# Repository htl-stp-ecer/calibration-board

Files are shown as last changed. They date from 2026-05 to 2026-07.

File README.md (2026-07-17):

<div align="center">

Calibration Board

# calibration-board

**A companion board for the KIPR Wombat: absolute position from optical flow, and a reference IMU good enough to calibrate the Wombat's own.**

KiCad PCB · STM32F722 firmware · On-board Madgwick fusion · Persistent flash calibration · USB-CDC to LCM bridge






> 📖 Platform documentation at [raccoon-docs.pages.dev](https://raccoon-docs.pages.dev/)

</div>

---

## What this is

There are two things a Wombat can't tell you well on its own.

The first is where it actually is. Wheel odometry integrates encoder ticks and trusts them, but wheels slip on seams, on poms and on ramps, and every slipped tick stays in the estimate for the rest of the run. Encoders measure the wheels, not the ground.

The second is whether its IMU is accurate. The Wombat's onboard IMU is fine for checking that a turn was roughly 90°. It isn't good enough to calibrate anything against.

This board addresses both, and it rides on the robot rather than sitting on a bench:

- A PAA5100 optical flow sensor tracks the table surface. Counts are scaled through a stored calibration into centimetres, which gives the robot an absolute position that doesn't depend on whether a wheel spun.
- An ICM-42688-P with Madgwick fusion on an M7 with an FPU provides a gyro reference accurate enough to calibrate the Wombat's onboard IMU against.

Hence the name. It isn't a board you calibrate, it's the board that does the calibrating.

### What it's for

- Calibrating the onboard IMU, with this board as the reference
- Motion teach-in, recording the trajectory that actually happened rather than the one the encoders inferred
- Automated setup routines. Botball allows automated routines during setup time, which is when a robot can locate and calibrate itself before the run starts

This repo isn't a template. It's a working board with an honest bring-up history attached. Read [Known limitations](#known-limitations) before fabbing one.

---

## Calibration that survives a power cycle

Most of the interesting work is in `app/src/paa_cal_module.c` and `app/inc/calib_store.h`.

Calibration lives in flash rather than in a startup routine. Sector 7 (0x08060000, 128 KB) holds a single 64-byte block: PAA scaling (`cx_per_cm`, `cy_per_cm`, `height_mm`), the gyro bias, a magic number, a schema version and a CRC32. The firmware fits in sectors 0 to 3, so 4 to 7 are free. A bad CRC or empty flash falls back to defaults and reports `valid = false`, so the caller knows it has never been calibrated instead of trusting garbage.

The board boots already calibrated. At startup the stored gyro bias is loaded straight into `imu_fusion_init()`, so there's no warm-up and no need to hold the robot still before a match.

Bias is learned continuously and persisted carefully. While the board is at rest, an exponential moving average runs on the raw gyro, and that average is the bias. It's subtracted before Madgwick and before anything is sent over USB. Auto-save only fires when the learned bias drifts more than 0.5 dps from the stored value, only while at rest so the value is trustworthy, and at most every 2 minutes. Each save costs a full sector erase, roughly 1 s and one P/E cycle, so the threshold and interval keep writes down to a few per large temperature swing. Gyro bias drifts around 0.05 dps/°C, which is what the thresholds are sized for.

Flash writes are deferred out of interrupt context into the main loop via a pending flag, because `HAL_FLASHEx_Erase` blocks.

At-rest detection uses a max-min spread across the gyro axes and accel magnitude, with time dwell and hysteresis. It takes about 0.5 s to declare the board still, and exits immediately on motion. Madgwick runs without a magnetometer at the ICM's 1 kHz ODR, so yaw drifts slowly while roll and pitch stay corrected against gravity. A filter step costs about 1 µs on the M7 at 216 MHz.

Commands over USB: `CMD_SET_PAA_CAL` stores new PAA scaling, `CMD_SAVE_GYRO_BIAS` persists the current at-rest average, `CMD_RESET_GYRO_BIAS` clears it. Telemetry goes the other way, with ORIENTATION frames (quaternion, bias, at-rest flag) at 100 Hz and PAA calibration telemetry at 1 Hz.

---

## How it fits together

```
PAA5100 ─┐                                              ┌─ raccoon/calib_board/paa/delta_x
         ├─ SPI ─► STM32F722 ──► USB-CDC ──► host ──────┤─ raccoon/calib_board/icm/accel
ICM-42688-P ─┘     fusion 1 kHz   binary     bridge     ├─ raccoon/calib_board/icm/gyro
                   cal in flash   frames                └─ raccoon/calib_board/status/*
```

`host/` is a C++ bridge (`raccoon-calib-bridge`) that reads binary frames from `/dev/ttyACM*` and republishes them as typed [raccoon-transport](https://github.com/htl-stp-ecer/raccoon-transport) messages. Calibration data flows on the same LCM channels as everything else in RaccoonOS, so BotUI or any other subscriber can plot it live. Status channels republish every second, which means a subscriber that starts late still picks up the current state instead of waiting for an event. A systemd unit is included.

### Firmware architecture

The module registry is Arduino-style. Each sensor is a `module_t` with `setup()` and `loop()`, registered in one array in `app/src/app.c`. An `enabled` flag parks a module without deleting it, which is how the dead BNO is handled.

Modules are started 25 ms apart rather than all at once. Every peripheral draws current at bring-up, and simultaneous init is a step load that can pull a marginal supply into brownout. Staggering flattens the ramp. The capacitor inrush at plug-in happens before this phase and isn't affected.

---

## Bring-up history

The board was designed around a Bosch BNO086, which does sensor fusion on-chip and outputs a quaternion directly. It never came up. After reset the INT line asserts, but the BNO never actively drives MISO, so every packet we read was a threshold artefact from a floating line. SPI mode, clock speed, pull-ups, boot delay and pin states were all ruled out in software, which left a suspected broken CS path. It's parked in the firmware with `.enabled = false /* BNO08x defekt */`.

The ICM-42688-P took over instead: raw 6-axis, with fusion left to us. That's why `imu_fusion.c` exists. Losing the chip that would have done fusion internally is what moved Madgwick onto the STM32, where the bias estimator could be added and the whole pipeline is visible rather than hidden behind a sensor hub.

The HSE crystal also refused to oscillate at first, leaving `HSEON=1, HSERDY=0` and dropping into `Error_Handler` on every boot. That turned out to be an oscillator ground problem and was fixed in the schematic. The firmware runs on HSE now.

---

## Repo layout

| Path | Contents |
|:-----|:---|
| `Firmware/` | STM32CubeMX CMake project, target STM32F722RET6. Capitalised folders are ST-generated, lowercase are ours |
| `Firmware/app/` | Module registry, fusion, calibration store, USB framing |
| `Firmware/drivers/` | Our chip drivers: `bno08x/`, `icm42688p/`, `paa5100/` |
| `Firmware/lib/sh2/` | CEVA BNO08x driver (git submodule) |
| `Firmware/scripts/` | build / flash / debug / uart / swo. Call these rather than ST tools directly |
| `host/` | C++ USB-CDC to raccoon-transport bridge, plus systemd unit |
| `IMU_Extendor_Board/` | KiCad 7+ project: schematic, PCB, BOM, gerbers in `production/` |
| `enclosure/` | OpenSCAD tray and lid, STL/STEP exports (M2 self-tapping, ~55x55 mm PCB) |
| `Component_Datasheets/` | Datasheets plus hand-written analysis (`external_clock_analysis.md`) |
| `docs/` | Toolchain setup, firmware workflow, hardware overview, coding conventions |

---

## Quick start

```bash
git submodule update --init --recursive   # sh2 + raccoon-transport

Firmware/scripts/build.sh          # cmake + ninja
Firmware/scripts/build-docker.sh   # same, in a container, no host arm-gcc needed
Firmware/scripts/flash.sh          # build + flash + verify + start over ST-LINK SWD
Firmware/scripts/uart.sh           # stream the debug console (J703, 115200 8N1)
```

Full setup for a fresh machine: [`docs/toolchain-setup.md`](docs/toolchain-setup.md).

### Catching boot output

Start `uart.sh` before `flash.sh`. The boot `printf` fires within milliseconds of reset, well before you can switch terminals. Two panes:

```bash
# Pane 1, left running:
Firmware/scripts/uart.sh
# Pane 2:
Firmware/scripts/flash.sh
```

If an expected printf never appears, the firmware is more likely hung before that line than the UART is broken. Init exposes debug globals (`g_bno_init_status`, `g_paa_init_status`, `g_bno_stage`, `g_paa_cal_loaded`) that you can read over SWD without re-flashing:

```bash
STM32_Programmer_CLI -c port=SWD mode=HOTPLUG -r32 <addr> 4
```

### The USER LED is a status channel

With no UART adapter attached, the LED is the only thing reporting anything:

| Pattern | Meaning |
|:---|:---|
| 100 ms on / 100 ms off (fast) | init OK, sensor answered, product IDs read |
| 500 ms on / 500 ms off (slow) | setup failed, INT line or clock path suspect |
| 50 ms on / 950 ms off (pulse) | unexpected init return code |

---

## Known limitations

Worth reading before you fab a board or trust a number.

- The BNO086 is dead and disabled. A broken CS path is the suspicion. Software causes were ruled out, so it needs a DMM on `PA4` to `BNO086 CSN` before anyone touches the firmware again.
- USB-C (J101) is not populated. The board runs off the ST-LINK debug cable, which caps its current budget and means it isn't standalone. J101 and the USBLC6 ESD diode need populating per the schematic before it can ride on a robot properly.
- SWO doesn't work with ST-LINK V2 clones. `swo_init` configures TPIU/ITM correctly, but the green clones expose a `T_JTDO` pin that isn't internally wired to their TRACESWO input, and reflashing official ST firmware doesn't fix it. Use UART4 instead, or a genuine STLINK-V3. `__io_putchar` writes to both sinks, so take whichever you can capture.
- PAA scaling depends on mount height. The defaults assume 19 mm. Changing the height changes counts-per-cm, so recalibrate via `CMD_SET_PAA_CAL` after any remount or the absolute position will be confidently wrong.
- The flash layout assumes small firmware. The calibration block sits in sector 7 because the code fits in sectors 0 to 3. Firmware growing past about 448 KB breaks that.
- Chip-select assignments aren't fully captured in the firmware. Cross-reference the KiCad schematic before wiring up a new sensor.
- `Firmware.ioc` is owned by CubeMX. Regenerating overwrites most of `Core/` and `Drivers/`, so keep code inside the `USER CODE BEGIN/END` markers, or put it in `app/` and call it from `app_main()`.
- Parts of the docs and code comments are in German. This was an internal engineering repo and we haven't translated it.

---

## Part of RaccoonOS

| Repository | What it is |
|:---|:---|
| [raccoon-transport](https://github.com/htl-stp-ecer/raccoon-transport) | The LCM messaging layer this board publishes into |
| [stm32-data-reader](https://github.com/htl-stp-ecer/stm32-data-reader) | Pi to STM32 SPI bridge on the robot itself |
| [raccoon-lib](https://github.com/htl-stp-ecer/raccoon-lib) | Core robotics library, odometry and heading control downstream of this |
| [raccoon-robots](https://github.com/htl-stp-ecer/raccoon-robots) | Real competition robots built on the platform |
| [botui](https://github.com/htl-stp-ecer/botui) | Wombat dashboard, can subscribe to these channels live |
| [documentation](https://raccoon-docs.pages.dev/) | Full platform docs |

---

Built by team `axht-3085`, the Botball team at HTL St. Pölten.

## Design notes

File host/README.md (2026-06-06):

# raccoon-calib-bridge

USB-CDC → `raccoon-transport` bridge for the calibration-board firmware
(`../Firmware`).  Reads binary frames from `/dev/ttyACM*`, publishes
typed messages on `raccoon/calib_board/...` channels, and reports board
+ per-sensor status on dedicated status channels.

## Channels

| Channel | Type | Units / payload |
|---|---|---|
| `raccoon/calib_board/icm/accel` | `vector3f_t` | g (x,y,z) |
| `raccoon/calib_board/icm/gyro` | `vector3f_t` | dps (x,y,z) |
| `raccoon/calib_board/icm/temperature` | `scalar_f_t` | °C |
| `raccoon/calib_board/paa/delta_x` | `scalar_i32_t`  | raw counts |
| `raccoon/calib_board/paa/delta_y` | `scalar_i32_t`  | raw counts |
| `raccoon/calib_board/paa/squal` | `scalar_i32_t`  | 0..169 surface qual. |
| `raccoon/calib_board/paa/shutter` | `scalar_i32_t`  | raw 16-bit |
| `raccoon/calib_board/paa/motion` | `scalar_i32_t`  | bitfield |
| `raccoon/calib_board/status/board` | `string_t` | `connected`/`disconnected` |
| `raccoon/calib_board/status/port` | `string_t` | `/dev/ttyACMn` or `(none)` |
| `raccoon/calib_board/status/icm` | `string_t` | `ok` / `init_failed:<reason>` |
| `raccoon/calib_board/status/paa` | `string_t` | `connected` / `absent` / `init_failed:<reason>` |
| `raccoon/calib_board/status/stats` | `string_t` | JSON (counters) |

All status channels are republished every 1 s so a subscriber that comes
up after the bridge can pick up current state without having to wait
for an event.

## Build

```bash
git submodule update --init --recursive   # first time only
scripts/build.sh                          # native build → build/raccoon-calib-bridge
CMAKE_BUILD_TYPE=Debug scripts/build.sh   # debug build
```

`scripts/build.sh` will auto-init the submodule and also accepts the
sibling `../../raccoon-transport` directory as a fallback when the
workspace is checked out flat.

## Run (foreground)

```bash
build/raccoon-calib-bridge                          # auto-detect /dev/ttyACM*
build/raccoon-calib-bridge --port /dev/ttyACM0      # explicit
CALIB_BRIDGE_LOG=debug build/raccoon-calib-bridge   # noisy
```

The bridge **runs even when the board is not connected** — it just
publishes `status/board = "disconnected"` and retries the open every
500 ms.  When the board appears it auto-attaches; when it disappears it
goes back to retrying.  Same for the PAA5100 (status frames from the
firmware report PAA connect/disconnect events mid-run).

## Install as systemd service

```bash
scripts/build.sh
scripts/install.sh           # asks for sudo
systemctl status   raccoon-calib-bridge
journalctl -u      raccoon-calib-bridge -f
```

Override defaults in `/etc/default/raccoon-calib-bridge`, then
`systemctl restart raccoon-calib-bridge`.

## Status semantics

* `status/board = connected`     — port open, bytes flowing
* `status/board = disconnected`  — port closed (either never opened, lost, or silence-timeout fired)
* `status/icm   = ok`            — ICM init reported OK (from firmware STATUS frame, or inferred from incoming ICM frames)
* `status/icm   = init_failed:…` — firmware reported a specific failure
* `status/paa   = connected`     — firmware STATUS frame reports PAA init OK
* `status/paa   = absent`        — firmware STATUS frame reports no PAA present
* `status/paa   = board_disconnected` — board itself is down; PAA state unknown

## Protocol

Frames are documented in `shared/calib_bridge/Framing.h` and **must stay
byte-identical** to `../Firmware/app/inc/framing.h`.  Same CRC, same
endianness, same payload layout.  If you change one, change the other.

## Layout

```
host/
├── CMakeLists.txt
├── README.md
├── scripts/
│   ├── build.sh
│   └── install.sh
├── shared/
│   └── calib_bridge/Framing.h     # frame format + decoders
├── src/
│   ├── main.cpp
│   └── calib_bridge/
│       ├── Application.{h,cpp}    # main loop, reconnect, status
│       ├── Channels.h             # channel name constants
│       ├── Config.{h,cpp}         # CLI + ENV config
│       ├── FrameDecoder.{h,cpp}   # sync/CRC/dispatch
│       ├── Publisher.{h,cpp}      # raccoon::Transport adapter
│       └── SerialPort.{h,cpp}     # /dev/ttyACM* RAII + autodetect
├── systemd/
│   └── raccoon-calib-bridge.service
└── third_party/
    └── raccoon-transport/   # git submodule
```

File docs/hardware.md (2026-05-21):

# Hardware Overview

The calibration board is a carrier PCB for the Raccoon Botball robot, designed to characterise IMU drift and bias prior to deployment. KiCad sources live in `IMU_Extendor_Board/`; BOM in `IMU_Extendor_Board.csv`, production gerbers and pick&place in `IMU_Extendor_Board/production/`.

## MCU

**STM32F722RET6** — Cortex-M7 @ up to 216 MHz, FPU (fpv5-sp-d16), 512 KB Flash, 256 KB RAM, LQFP-64. Powered via 3.3 V (linear regulator on board; datasheet in `Component_Datasheets/3V3_Linear_Regulator_files/`).

### Pin assignments (from `Firmware.ioc`)

| Function | Pins |
|---|---|
| **SWD** | PA13 (SWDIO), PA14 (SWCLK), PB3 (SWO) |
| **UART4** (debug console) | PA0 (TX → adapter RX), PA1 (RX ← adapter TX), 115200 8N1, broken out on J703. Stream with `Firmware/scripts/uart.sh`. Common GND required, **do not** also bridge VCC if board is powered via ST-LINK. |
| **SPI1** | PA5 (SCK), PA6 (MISO), PA7 (MOSI) — IMU #1 candidate bus |
| **SPI2** | PB10 (SCK), PC2 (MISO), PC3 (MOSI) — IMU #2 candidate bus |
| **SPI3** | PC10 (SCK), PC11 (MISO), PC12 (MOSI) — IMU #3 candidate bus |
| **USB OTG FS** | PA9 (VBUS), PA11 (D-), PA12 (D+) |
| **External interrupts** | PA15 (EXTI15), PC4 (EXTI4) — likely IMU INT lines |
| **HSE** | PH0/PH1 (main oscillator) |
| **LSE** | PC14/PC15 (RTC oscillator) |
| **GPIO outputs** | PA2, PA3, PA4, PB0–B2, PB11–B15, PC6–C9, PD2 — CS lines, LEDs, IMU reset/boot |

Three independent SPI buses suggest the board is wired for simultaneous evaluation of multiple IMUs; chip-select assignments are not yet captured in the firmware and need cross-referencing with the KiCad schematic.

## Candidate IMUs

Datasheets present in `Component_Datasheets/` for both options:

- **Bosch BNO080 / BNO085** — sensor fusion built in (quaternion output over SPI/I2C/UART, "Sensor Hub"). Crystal: ECS-327KE 32.768 kHz (datasheet present).
- **TDK InvenSense ICM-42688-P** — 6-axis (3-axis accel + 3-axis gyro), low-noise. Raw output, fusion done on host.

Both can be populated alongside each other on the same carrier (one per SPI bus), enabling side-by-side bias/drift comparison.

## Oscillators

- **ABM8G-12.000MHZ-18-D2Y-T** — 12 MHz HSE for the STM32 (datasheet: `ABM8G-12.000MHZ-...pdf`)
- **ABM8-272-T3** — additional crystal, role TBD from schematic (likely IMU clock)
- **ECS-327KE** — 32.768 kHz, used by BNO080/085 per `external_clock_analysis.md`

The hand-written analysis in `Component_Datasheets/external_clock_analysis.md` documents the clocking strategy — read it before changing any RCC config in `Firmware.ioc`.

## Power

3.3 V linear regulator (see `3V3_Linear_Regulator_files/`); USB OTG FS handles bus-powered operation.

## KiCad project

Open `IMU_Extendor_Board/IMU_Extendor_Board.kicad_pro` in KiCad 7+. Custom symbols and footprints in `Component_Lib/`; design rules in `IMU_Extendor_Board.kicad_dru`. Production drop is `production/` (zipped as `production.zip`).

For agent-friendly inspection of the schematic, install `kicad-cli` (`sudo apt install kicad-cli`) and export to PDF/netlist:

```bash
cd IMU_Extendor_Board
kicad-cli sch export pdf -o schematic.pdf IMU_Extendor_Board.kicad_sch
kicad-cli sch export netlist -o schematic.net IMU_Extendor_Board.kicad_sch
kicad-cli sch export bom -o bom.csv IMU_Extendor_Board.kicad_sch
```

The raw `.kicad_sch` is S-expression text (~21k lines) — parseable but verbose; prefer the exports for any structural analysis.

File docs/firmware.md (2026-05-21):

# Firmware Workflow

Day-to-day build, flash, and debug for the STM32F722RET6 firmware. For one-time setup see `toolchain-setup.md`.

## Helper scripts

All workflow goes through `Firmware/scripts/`. They work from any CWD, source `_common.sh` for paths, and filter `libusb:` noise + ANSI escapes out of ST tool output.

| Script | What it does |
|---|---|
| `build.sh [Debug\|Release]` | Configure (if needed) + ninja build. Default: Debug. |
| `build-docker.sh [Debug\|Release]` | Same as `build.sh` but inside a Debian builder container — no host arm-none-eabi-gcc / cmake / ninja required. Image is auto-built on first run. |
| `flash.sh [Debug\|Release]` | `build.sh` then flash + verify + start on SWD. |
| `reset.sh` | Software-reset target. No re-flash. |
| `erase.sh` | Full chip erase under reset. Use when target is bricked / unresponsive. |
| `gdbserver.sh` | Foreground `ST-LINK_gdbserver` on `:61234`. For IDE external-server debug configs. |
| `debug.sh` | `build.sh` + gdbserver in background + interactive `arm-none-eabi-gdb` with `load` and `tbreak main`. |
| `uart.sh` | Stream UART4 `printf` output (J703, 115200 8N1) from the USB-UART adapter. Auto-detects CP2102, falls back to `/dev/ttyUSB0`. Logs to `$BUILD_DIR/uart.log`. |
| `swo.sh` | Stream SWO/ITM trace from PB3 via `STM32_Programmer_CLI -startswv`. **Requires a genuine ST-LINK V3** — most ST-LINK V2 clones (green USB stick) don't route TRACESWO internally. Logs to `$BUILD_DIR/swv.log`. See troubleshooting below. |

### Env overrides

| Var | Default | Effect |
|---|---|---|
| `BUILD_TYPE` | `Debug` | Selects CMake preset and build dir |
| `SWD_FREQ_KHZ` | `4000` | ST-LINK SWD clock |
| `GDB_PORT` | `61234` | Port for `gdbserver.sh` / `debug.sh` |
| `PROG_CLI`, `GDB_SERVER`, `GDB` | binaries on PATH | Override tool binaries |
| `UART_DEV` | auto (CP2102) / `/dev/ttyUSB0` | Serial device for `uart.sh` |
| `UART_BAUD` | `115200` | Baud rate for `uart.sh` (must match `MX_UART4_Init`) |
| `SYSCLK_MHZ` | `192` | HCLK in MHz for `swo.sh` (must match `swo_init()` call) |
| `SWV_PORT` | `0` | ITM stimulus port for `swo.sh` |

Example: release build, flashed at slower clock:

```bash
SWD_FREQ_KHZ=1800 Firmware/scripts/flash.sh Release
```

### Docker builder

`Firmware/Dockerfile` defines a `debian:trixie-slim` image with `gcc-arm-none-eabi` 14.2 + cmake + ninja. The host source tree is bind-mounted at **the same absolute path** inside the container, so the paths CMake bakes into `CMakeCache.txt` are valid both inside and outside the container. Consequence: you can freely alternate `build-docker.sh` and `build.sh` — the build cache is shared and reused, no clean-and-reconfigure dance.

Override the image tag with `BUILD_DOCKER_IMAGE=…`. Rebuild the image after editing the Dockerfile with `docker build -t raccoon-calibration-firmware:latest Firmware/`.

Flashing still happens host-side (`flash.sh`) — the container deliberately does **not** contain `STM32_Programmer_CLI`. ST's license forbids redistributing it, and USB passthrough for ST-LINK is fragile across hosts.

## Project structure

```
Firmware/
├── CMakeLists.txt             # User-editable
├── CMakePresets.json          # Debug/Release presets, Ninja, gcc-arm-none-eabi toolchain
├── Firmware.ioc               # STM32CubeMX project — regenerates Core/ + Drivers/
├── STM32F722XX_FLASH.ld       # Linker script (512 KB flash, 256 KB RAM)
├── startup_stm32f722xx.s      # Reset handler + vector table
├── cmake/
│   ├── gcc-arm-none-eabi.cmake     # Toolchain file (cortex-m7 + fpv5-sp-d16)
│   └── stm32cubemx/                # CubeMX-generated HAL driver list
├── Core/
│   ├── Inc/{main,stm32f7xx_hal_conf,stm32f7xx_it}.h
│   └── Src/{main,stm32f7xx_hal_msp,stm32f7xx_it,syscalls,sysmem,system_stm32f7xx}.c
├── Drivers/
│   ├── CMSIS/                       # ARM CMSIS + STM32F7xx device headers
│   └── STM32F7xx_HAL_Driver/        # ST HAL sources
└── scripts/                         # See above
```

**Touch-zone rules:**

- `Core/Src/main.c` and friends: only edit inside `/* USER CODE BEGIN ... */` … `/* USER CODE END ... */` markers. CubeMX overwrites everything outside on regeneration.
- `Firmware.ioc`: edit only in STM32CubeMX. Regenerate with **Project → Generate Code** from the CubeMX UI (or `stm32cubemx` CLI). Commit the regenerated diff together with the `.ioc` change.
- `cmake/stm32cubemx/`: auto-generated. Do not hand-edit.
- `CMakeLists.txt`: user-owned. Add your sources to `target_sources()`, includes to `target_include_directories()`.

## CLion integration

The `.idea/debugServers/ST_LINK.xml` already points at the installed CubeCLT paths. Recommended run-configs:

**1. Flash (Shell Script)**
- Script path: `$ProjectFileDir$/scripts/flash.sh`
- Working dir: `$ProjectFileDir$`
- Before launch: *(none — `flash.sh` builds itself)*

**2. Debug (Embedded GDB Server)**
- Target: `Firmware` (CMake)
- Executable binary: `Firmware`
- `'target remote' args`: `tcp:localhost:61234`
- GDB Server: `$ProjectFileDir$/scripts/gdbserver.sh`
- Reset command: `monitor reset`

With these two, "Run" flashes, "Debug" attaches GDB through the same gdbserver the script starts.

## Headless / AI agent workflow

Everything runs without CLion. Example one-shot edit→flash cycle for an agent:

```bash
# edit code
$EDITOR Firmware/Core/Src/main.c
# build + flash + run, single command, works from any CWD
Firmware/scripts/flash.sh
# observe printf output via UART4 on PA0/PA1 (J703) — start before flash to catch boot lines
Firmware/scripts/uart.sh
```

`__io_putchar` writes to both SWO/ITM (PB3) and UART4 — printf goes out whichever path you can capture. SWO needs a working trace probe (see troubleshooting); UART4 needs only a 3.3 V USB-UART adapter on J703 with GND tied to board ground.

For a brick (target won't enumerate on SWD under normal connect), use connect-under-reset path:

```bash
Firmware/scripts/erase.sh    # uses mode=UR (connect-under-reset) + full erase
Firmware/scripts/flash.sh    # then re-flash
```

## Troubleshooting

| Symptom | Likely cause | Fix |
|---|---|---|
| `Error: No STM32 target found` | Target unpowered, SWD wiring wrong, or BOOT0 stuck | Check 3V3 rail, SWCLK/SWDIO continuity (PA14/PA13), tie BOOT0 low |
| `libusb: error … requires write access` | udev rules not applied | `sudo udevadm control --reload-rules && sudo udevadm trigger` + re-plug ST-LINK |
| `Duplicate preset: "Debug"` from cmake | Local `CMakeUserPresets.json` collides with `CMakePresets.json` | Rename local presets (e.g. `Debug-local`) or delete the user file |
| Verify fails after download | Wrong target / corrupted flash sector | `erase.sh` then retry |
| `swo.sh` prints "Reception Started" then nothing | Clone ST-LINK V2 (green USB stick) — `T_JTDO` pin exists but isn't internally wired to the probe's TRACESWO input. Reflashing the official ST firmware (`/opt/st/stm32cubeclt_1.21.0/STLinkUpgrade.sh -force_prog`) does **not** fix this; the limitation is hardware. | Use `uart.sh` instead, or get an STLINK-V3MINIE. |
| `uart.sh` shows 0 bytes | **UART4 is verified working** — if you see nothing, the cause is almost always one of: (1) `uart.sh` was started *after* `flash.sh`, missing the boot-time burst (most common — the loop's `printf`s may also stop appearing if a driver init blocks the main loop from being reached); (2) **GND not bridged** between USB-UART adapter and board (silent failure); (3) baudrate mismatch (must be 115200, see `MX_UART4_Init`); (4) firmware actually hangs before reaching the first `printf` (rare — `swo_init` + `setvbuf` are the only things ahead of `printf("[boot] …")`). | Start `uart.sh` **before** `flash.sh`, confirm shared GND. To distinguish "MCU hung" from "UART broken", read `g_bno_init_status` / `g_paa_init_status` / `g_bno_stage` via `STM32_Programmer_CLI -c port=SWD mode=HOTPLUG -r32 <addr> 4` — if the stage variable advances, the firmware runs and the silence is on the host/wiring side. |
| GDB server: `Port 61234 already in use` | Previous `gdbserver.sh` still running | `pkill -f ST-LINK_gdbserver` or set `GDB_PORT=61235` |

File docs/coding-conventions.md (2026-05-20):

# Firmware coding conventions

Applies to all C code under `Firmware/` **except** `Firmware/Core/`,
`Firmware/Drivers/`, and `Firmware/lib/` — those are STM32CubeMX-generated or
third-party and follow their upstream styles.

## Folder layout

```
Firmware/
├── Core/                     # STM32CubeMX-owned. Hands off (regenerates).
├── Drivers/                  # ST HAL + CMSIS. Hands off (regenerates).
├── app/                      # Application logic (state machines, glue).
│   ├── inc/                  # Public headers
│   └── src/                  # Implementations
├── drivers/                  # Project-owned hardware drivers.
│   └── <chip>/
│       ├── inc/<chip>.h      # Public API
│       └── src/<chip>.c
├── lib/                      # Third-party (submodules, vendored libs).
└── scripts/                  # Build / flash / debug helpers.
```

Rule of thumb: **capitalised folders are ST-generated, lowercase folders are
ours**. New code goes into lowercase.

## Naming

| Kind | Style | Example |
|---|---|---|
| Functions, variables | `snake_case` | `bno08x_read_quat()` |
| Module-public API | `<module>_` prefix | `bno08x_init()`, `app_main()` |
| Module-internal | `static`, no prefix | `static void parse_report(...)` |
| Types | `snake_case_t` | `bno08x_status_t` |
| Macros, constants | `UPPER_SNAKE` | `BNO08X_MAX_FRAME` |
| Enum values | `UPPER_SNAKE`, type-prefixed | `BNO08X_OK` |
| Files | lowercase, match module name | `bno08x.c`, `bno08x.h` |

Never `typedef` away pointers (no `bno08x_t *` hidden as `bno08x_handle`) —
explicit pointers read better.

## Headers

- Use `#pragma once`, not include guards. GCC supports it, less boilerplate.
- Public API only in `inc/`. Internal helpers in `src/`, optionally as
  `<module>_priv.h` next to the `.c`.
- Forward-declare in headers where possible; full `#include` only when the
  header needs the type's layout.
- One module = one `.c` + one `.h`. If a `.c` grows beyond ~500 lines, split.

## Functions and state

- Everything file-local is `static`. If something isn't in the public header,
  it must be `static`.
- No global variables outside of HAL-generated handles in `Core/`. Module
  state goes in a `static` struct inside the `.c`.
- Functions return `0` on success and negative `errno`-style codes on failure,
  or a dedicated `<module>_status_t` enum (preferred when codes are
  module-specific). Pick one per module and stick to it.
- Out-parameters via pointer, never by returning structs by value (varies
  across ABIs and copies on Cortex-M).

## main.c and USER CODE markers

- `Core/Src/main.c` is regenerated by CubeMX. The `/* USER CODE BEGIN ... */`
  markers are the only safe place for hand edits — anything outside gets
  overwritten.
- Keep `main.c` thin: peripheral init (CubeMX does this) + one call to
  `app_main()` in `USER CODE BEGIN 2`. Real logic lives in `app/`.
- Don't put driver-level code into `USER CODE` blocks. Add a module under
  `drivers/<chip>/` and call it from `app/`.

## Comments

- Default: no comments. Names should carry the meaning.
- Write a comment only when the **why** is non-obvious: a hidden constraint
  from a datasheet, a workaround for a known erratum, a subtle ordering
  requirement. Reference the source (`§7.3.2 of DS13855`) when relevant.
- Don't comment what the code does. Don't reference tickets, PRs, or
  "added for X" — that's git/PR territory.

## Includes order

```c
#include "this_module.h"        /* own header first — verifies it's self-contained */

#include <stdint.h>             /* C standard library */
#include <string.h>

#include "main.h"               /* HAL / ST */
#include "stm32f7xx_hal.h"

#include "sh2.h"                /* third-party */

#include "app.h"                /* other project modules */
```

Blank line between groups.

## Build hygiene

- Build artifacts go to `Firmware/build/<BuildType>/`. Never commit them.
- The `.ioc` file is owned by CubeMX; don't hand-edit unless you know what
  you're undoing on the next regen.
- `CMakeUserPresets.json` is local-only (gitignored). Use it for per-machine
  paths; never `CMakePresets.json`.

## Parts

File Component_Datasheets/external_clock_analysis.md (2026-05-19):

# External Clock vs. Internal Clock — Impact Analysis
## BNO08X & ICM-42688-P for Dual-IMU Robotics

---

## 1. ICM-42688-P

### 1.1 Clock Source Specifications (from Table 4, section 3.3.2)

| Parameter | Internal RCOSC (CLK_SEL=00) | Internal PLL (CLK_SEL=01, gyro active) | External CLKIN |
|---|---|---|---|
| Initial tolerance at 25 °C | ±3 % | ±1.5 % | — |
| Variation over temp (−40 to +85 °C) | ±3 % | ±2 % | — |
| ODR uncertainty (section 4.10) | **±8 %** (±80 000 ppm) | **±1 %** (±10 000 ppm) | **±50 ppm** (with 50 ppm source) |
| Clock frequency | internal | internal | 31–50 kHz, typ. 32 kHz |

> The datasheet (section 4.10) explicitly states ODR uncertainty can be as high as ±8 % in RCOSC mode and ±1 % in PLL mode. A 50 ppm CLKIN source reduces this to ±50 ppm in both modes.

---

### 1.2 Calculations — ICM-42688-P

**Assumptions:** nominal ODR = 1000 Hz, robotics run of T = 10 s, host uses sensor sample count as time reference (no external timestamping).

#### 1.2.1 Sample count drift

| Clock source | Actual ODR range | Samples in 10 s | Error vs. 10 000 samples |
|---|---|---|---|
| RCOSC (±8 %) | 920–1080 Hz | 9 200–10 800 | **±800 samples** |
| PLL (±1 %) | 990–1010 Hz | 9 900–10 100 | ±100 samples |
| CLKIN 50 ppm | 999.95–1000.05 Hz | 9 999.5–10 000.5 | **±0.5 samples** |

#### 1.2.2 Timing error (dead-reckoning with sample count × nominal dt)

Formula: `time_error = T × clock_error_fraction`

| Clock source | Time error after 10 s | Time error after 60 s |
|---|---|---|
| RCOSC (±8 %) | **±800 ms** | **±4.8 s** |
| PLL (±1 %) | ±100 ms | ±600 ms |
| CLKIN 50 ppm | **±0.5 ms** | **±3 ms** |

#### 1.2.3 Gyroscope angle integration error

Dead-reckoning angle: if the sensor's dt is wrong, integrated heading is wrong by the same fraction.

Formula: `angle_error = total_angle_turned × clock_error_fraction`

**Scenario A — single 360° turn taking 1 s:**

| Clock source | Angle error |
|---|---|
| RCOSC (±8 %) | **±28.8°** |
| PLL (±1 %) | ±3.6° |
| CLKIN 50 ppm | **±0.018°** |

**Scenario B — 90° turn (typical Botball maneuver) at 180 °/s:**

| Clock source | Angle error |
|---|---|
| RCOSC (±8 %) | **±7.2°** |
| PLL (±1 %) | ±0.9° |
| CLKIN 50 ppm | **±0.0045°** |

#### 1.2.4 Sensitivity (scale factor) error from clock

From section 4.10: "Any clock uncertainty directly impacts gyroscope sensitivity at the system level."  
The scale factor error is proportional to ODR error.

| Clock source | Gyro sensitivity error |
|---|---|
| RCOSC | ±8 % |
| PLL | ±1 % |
| CLKIN 50 ppm | ±0.005 % |

#### 1.2.5 ODR Frequency Scaling with CLKIN

When CLKIN ≠ 32 kHz, actual ODR scales linearly (section 12.5):

```
ODR_actual = ODR_nominal × (f_CLKIN_kHz / 32)
```

Example: CLKIN = 32.768 kHz → ODR at nominal 1000 Hz = 1000 × (32.768/32) = **1024 Hz**  
This is predictable and compensatable; internal clock drift is not.

---

### 1.3 Improvement Factor — CLKIN vs. Internal

| Comparison | ODR improvement | Timing improvement |
|---|---|---|
| CLKIN over RCOSC | **1 600×** (80 000 ppm → 50 ppm) | **1 600×** |
| CLKIN over PLL | **200×** (10 000 ppm → 50 ppm) | **200×** |

---

## 2. BNO08X

### 2.1 Clock Source Options (section 1.2.1, Figures 1-7 to 1-10)

| Source | CLKSEL0 | CLKSEL1 | Notes |
|---|---|---|---|
| Crystal 32.768 kHz | 0 or NC | Connected to crystal | Recommended: 50 ppm, 12.5 pF load |
| External clock signal | 1 | 1 | Input on XIN32 (pin 27) |
| Internal oscillator | 1 | 0 or NC | **Not usable with UART-SHTP or UART-RVC** |

> CEVA recommends 50 ppm tolerance for external clock/crystal.

### 2.2 Performance Specifications

The performance table (Figure 6-14, section 6.7) is explicitly stated to apply **when using an external clock or crystal**.  
No separate performance specification is provided for the internal oscillator.

| Sensor output | Metric | Value (external clock/crystal) |
|---|---|---|
| Rotation Vector | Dynamic rotation error | 3.5° |
| Rotation Vector | Static rotation error | 2.0° |
| Gaming Rotation Vector | Dynamic non-heading error | 2.5° |
| Gaming Rotation Vector | Static non-heading error | 1.5° |
| Gaming Rotation Vector | **Heading drift** | **0.5°/min** |
| Geomagnetic Rotation Vector | Dynamic rotation error | 4.5° |
| Gyroscope | Dynamic accuracy | 3.1°/s |
| Accelerometer | Dynamic accuracy | 0.35 m/s² |

### 2.3 Calculations — BNO08X

The BNO08X runs its SH-2 fusion firmware off its reference clock. The clock feeds both sensor sampling timing and the algorithm's internal time reference.

#### 2.3.1 Heading drift over time

With external 50 ppm clock (spec):

| Time | Max heading drift |
|---|---|
| 1 min | 0.5° |
| 2 min (Botball match) | **1.0°** |
| 5 min | 2.5° |

With internal oscillator — no official figure given. Typical RC oscillators drift ±1–3 % from nominal. Using conservative ±1 % as an estimate (consistent with what similar CEVA/Bosch parts specify):

| Time | Estimated heading drift (internal, ±1 %) |
|---|---|
| 1 min | ~30–150× worse, estimated **15–75°/min** |
| 2 min (Botball match) | estimated **30–150°** cumulative |

> These internal clock figures are **estimated** — the BNO08X datasheet does not publish internal oscillator accuracy. The only official performance numbers are for external clock/crystal.

#### 2.3.2 Timestamp accuracy

The BNO08X attaches timestamps to sensor reports (SHTP protocol). With a 50 ppm external clock:

| Scenario | Timestamp error after 10 s | After 60 s |
|---|---|---|
| External 50 ppm | ±0.5 ms | ±3 ms |
| Internal oscillator (est. ±1 %) | ±100 ms | ±600 ms |

---

## 3. Dual-IMU Fusion — Synchronization Impact

Your setup uses both IMUs simultaneously to combine their strengths (BNO08X: stable fused orientation; ICM-42688-P: low-noise raw 6-axis at high rate). Synchronization between them is critical for correct data fusion.

### 3.1 Without shared external clock

Each sensor runs on its own independent clock:
- ICM-42688-P internal RCOSC: up to ±8 % ODR
- BNO08X internal oscillator: unknown, estimated ±1 %
- Relative clock error: up to ±9 % combined

**Sample alignment error between IMUs (no shared clock, RCOSC worst case):**

| ODR | Nominal sample period | Max alignment error | After 1 s |
|---|---|---|---|
| 100 Hz | 10 ms | ±9 % × 10 ms = ±0.9 ms per sample | Samples can differ by up to 90 ms in accumulated timing |
| 1000 Hz | 1 ms | ±0.09 ms per sample | up to 90 ms accumulated |

After just 1 second, the two sensors' sample clocks can be 90 ms apart from each other. Any data fusion algorithm that assumes "simultaneous" samples will be correlating data that is up to 90 ms apart.

### 3.2 With shared external 32.768 kHz clock

Both IMUs locked to the same reference:
- ICM-42688-P: ODR error ±50 ppm
- BNO08X: timestamp error ±50 ppm
- Relative alignment error: < ±100 ppm combined

| ODR | Nominal sample period | Max alignment error (shared clock) |
|---|---|---|
| 100 Hz | 10 ms | ±1 µs |
| 1000 Hz | 1 ms | ±0.1 µs |

Samples from both IMUs are effectively simultaneous.

### 3.3 Synchronization improvement summary

| Scenario | Sample alignment error (1 s) | Improvement |
|---|---|---|
| No external clock (RCOSC) | ~90 ms | — |
| No external clock (PLL) | ~10 ms | 9× |
| Shared 50 ppm CLKIN | **< 0.1 ms** | **900×** |

---

## 4. Verdict for Botball Robotics

| Aspect | Without external clock | With external 32.768 kHz clock |
|---|---|---|
| ICM-42688-P ODR accuracy | ±8 % (RCOSC) or ±1 % (PLL) | **±0.005 %** |
| Dead-reckoning heading error per 90° turn | ±7.2° (RCOSC) | **±0.0045°** |
| BNO08X heading drift (2-min run) | unknown / possibly >30° | **≤1.0°** |
| Dual-IMU sample alignment after 1 s | up to 90 ms offset | **< 0.1 ms** |
| Sensor fusion quality | severe interpolation required | essentially perfect alignment |

**Conclusion:** For a dual-IMU robotics application using dead-reckoning and sensor fusion, an external 32.768 kHz clock (50 ppm) shared between both IMUs makes a very large practical difference:
- ICM-42688-P ODR accuracy improves by **200–1600×**
- Sample alignment between the two IMUs improves by ~**900×**
- BNO08X performance specs are only guaranteed with external clock/crystal
- The BNO08X internal oscillator is explicitly forbidden for UART-SHTP and UART-RVC use cases

The external clock hardware cost is a single oscillator (e.g., SiT1532 or similar 32.768 kHz TCXO) plus routing — a very worthwhile investment given the performance gains.

---

*Sources: BNO08X Datasheet Rev. 1.17 (CEVA/Hillcrest), ICM-42688-P Datasheet Rev. 1.6 (TDK InvenSense)*

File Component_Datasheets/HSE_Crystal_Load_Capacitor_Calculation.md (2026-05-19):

# HSE Lastkondensator-Berechnung — ABM8G-12.000MHZ-18-D2Y-T an STM32F411

## Teilenummer-Dekodierung

```
ABM8G - 12.000MHz - 18 - D - 2 - Y - T
         │           │    │   │   │   └─ Tape & Reel (1k/reel)
         │           │    │   │   └───── Freq.-Stabilität: ±30 ppm
         │           │    │   └───────── Freq.-Toleranz: ±20 ppm
         │           │    └───────────── Betriebstemp.: D = -40 … +85 °C
         │           └────────────────── Lastkapazität: 18 pF
         └────────────────────────────── Frequenz: 12,000 MHz
```

---

## Kristall-Parameter (aus Datenblatt)

| Parameter | Wert |
|---|---|
| Frequenz | 12,000 MHz |
| Betriebsmodus | Fundamental |
| Lastkapazität C_L | **18 pF** |
| Shunt-Kapazität C_0 (max) | 5,0 pF |
| Serienersatzwiderstand R_1 (max @ 12 MHz) | **120 Ω** |
| Antriebspegel | 10 … **100 µW** |
| Betriebstemperatur (Option D) | -40 … +85 °C |
| Frequenztoleranz (Option 2) | ±20 ppm |
| Frequenzstabilität (Option Y) | ±30 ppm |
| Gehäuse | 3,2 × 2,5 × 1,0 mm |

---

## Schaltungstopologie — Pierce-Oszillator

```
OSC_IN ──┬── C1 ──┬── GND
         │        │
        [Quarz]  C_stray (parasitär)
         │        │
OSC_OUT ─┴── C2 ──┴── GND
```

Beide Kondensatoren C1 und C2 werden gleich gewählt (C1 = C2 = C_ext).

---

## Formel

Die effektive Lastkapazität, die der Quarz „sieht":

```
C_L = (C1 × C2) / (C1 + C2) + C_stray
```

Mit C1 = C2 = C_ext vereinfacht zu:

```
C_L = C_ext / 2 + C_stray
```

Aufgelöst nach C_ext:

```
C_ext = 2 × (C_L − C_stray)
```

---

## Streukapazität C_stray

| Quelle | Typischer Wert |
|---|---|
| STM32F411 OSC_IN Pin-Kapazität | ~2 pF |
| STM32F411 OSC_OUT Pin-Kapazität | ~2 pF |
| PCB-Leiterbahn / Pad-Streukapazität | ~1–2 pF |
| **Summe C_stray** | **~3 … 5 pF** |

> ST AN2867 gibt ~2 pF pro Pin als typischen Wert für STM32-Familien an.
> Für ein 2-Lagen-PCB wird **C_stray = 4 pF** als realistischer Mittelwert angenommen.

---

## Berechnung

### Nennwert-Berechnung (C_stray = 4 pF)

```
C_ext = 2 × (18 pF − 4 pF)
C_ext = 2 × 14 pF
C_ext = 28 pF
```

Nächster E12-Normwert: **27 pF**

### Verifikation mit C_ext = 27 pF

```
C_L_eff = 27 pF / 2 + 4 pF = 13,5 pF + 4 pF = 17,5 pF  (−2,8 % vom Sollwert)
```

### Sensitivitätsanalyse

| C_stray | C_ext (berechnet) | Nächster E12-Wert | C_L_eff | Abweichung |
|---|---|---|---|---|
| 3 pF | 30 pF | 30 pF | 18,0 pF | 0 % ✓ |
| **4 pF** | **28 pF** | **27 pF** | **17,5 pF** | **−2,8 %** |
| 5 pF | 26 pF | 27 pF | 18,5 pF | +2,8 % |

27 pF liegt im Zentrum der C_stray-Unsicherheit und ist der robusteste Normwert.
Die frequenzmäßige Auswirkung einer ±3 %-Abweichung bei C_L ist kleiner als die
Frequenztoleranz des Quarzes (±20 ppm) — unkritisch.

---

## Anlaufbedingung (Negativwiderstand-Prüfung)

Der Pierce-Oszillator startet sicher, wenn gilt:

```
gm_vorhanden > gm_min = SF × R1 × (ω × C_ext)²
```

Mit Sicherheitsfaktor SF = 5, R1 = 120 Ω, C_ext = 27 pF, ω = 2π × 12 MHz:

```
ω = 2π × 12 × 10⁶ = 75,40 × 10⁶ rad/s

ω × C_ext = 75,40 × 10⁶ × 27 × 10⁻¹² = 2,036 × 10⁻³ S

gm_min = 5 × 120 Ω × (2,036 × 10⁻³)²
       = 600 × 4,144 × 10⁻⁶
       = 2,49 × 10⁻³ A/V
       ≈ 2,5 mA/V
```

Der STM32F411 HSE-Oszillator liefert typisch **10–25 mA/V** (gem. AN2867),
also einen Sicherheitsfaktor von ca. 4–10× über dem Minimum. Anlauf ist gesichert.

> Hinweis: Der R_1 von 120 Ω ist höher als beim vorherigen Kristall (50 Ω),
> daher ist das gm_min hier ~12× größer. Der Anlaufspielraum ist ausreichend,
> aber geringer als bei Quarzen mit niedrigerem ESR.

---

## Antriebspegel-Abschätzung (kritisch)

```
P_drive ≈ ½ × R1 × (ω × C_L × V_pp)²
```

| V_pp | P_drive | Bewertung |
|---|---|---|
| 0,7 V | 43 µW | ✓ innerhalb Spec (10–100 µW) |
| 0,9 V | 90 µW | ✓ knapp innerhalb Spec |
| 1,0 V | **111 µW** | **✗ überschreitet 100 µW max** |
| 1,5 V | 250 µW | ✗ deutlich zu hoch |

**Rechenweg für V_pp = 1,0 V:**
```
ω × C_L = 75,40 × 10⁶ × 18 × 10⁻¹² = 1,357 × 10⁻³ S

P_drive = ½ × 120 × (1,357 × 10⁻³ × 1,0)²
        = 60 × 1,841 × 10⁻⁶
        = 110,5 µW  → überschreitet Max. von 100 µW
```

> **Achtung:** Der maximale Antriebspegel dieses Quarzes beträgt nur 100 µW.
> Der STM32F411-Oszillator kann bei 3,3 V Versorgung Amplituden von 1–2 V
> erzeugen, was den Quarz übersteuert und seine Lebensdauer verkürzt.
>
> **Empfehlung:** Einen Serienwiderstand R_S = 100 … 200 Ω in Serie mit
> OSC_IN schalten (zwischen MCU-Pin und Quarz). Dies dämpft die Amplitude
> und begrenzt den Antriebspegel. Typischer Startwert: **R_S = 100 Ω**.

### Antriebspegel mit R_S = 100 Ω (bei V_pp = 1,0 V)

Der Strom durch den Kristall-Zweig:

```
I_peak = V_pp / (R1 + R_S) × (ω × C_L) / ω  ... (vereinfacht für Abschätzung)
P_crystal ≈ ½ × R1 × I_peak²
          = ½ × R1 / (R1 + R_S)² × (V_pp × ω × C_L)²
          = ½ × 120 / (120 + 100)² × (1,357 × 10⁻³)²
          = 60 / 48400 × 1,841 × 10⁻⁶  ... (inkl. Faktor V²)
```

Vereinfachte Näherung: P skaliert mit (R1 / (R1+R_S)²) × V_pp²:

```
P_drive_mit_RS ≈ P_drive_ohne_RS × R1 / (R1 + R_S)
               = 110,5 µW × 120 / 220
               ≈ 60 µW  ✓
```

Mit R_S = 100 Ω liegt der Antriebspegel bei ~60 µW — sicher im Spec-Fenster.

---

## Ergebnis

| Bauteil | Wert | Toleranz | Dielektrikum |
|---|---|---|---|
| C1 (OSC_IN nach GND) | **27 pF** | ±5 % | C0G/NP0 |
| C2 (OSC_OUT nach GND) | **27 pF** | ±5 % | C0G/NP0 |
| R_S (in Serie mit OSC_IN) | **100 Ω** | ±5 % | — |

**C0G/NP0 zwingend erforderlich** — X5R/X7R haben spannungs- und
temperaturabhängige Kapazität und verschlechtern die Frequenzgenauigkeit.

**Layout-Hinweise:**
- C1 und C2 so nah wie möglich an die Quarz-Pads platzieren
- R_S direkt am OSC_IN-Pin des STM32 (nicht am Quarz-Pin) platzieren
- Leiterbahnen zwischen Quarz und MCU-Pins so kurz wie möglich halten
- Kein Ground-Pour direkt unter den Quarz-Leiterbahnen (erhöht C_stray)
- Quarz und Kondensatoren mit eigenem GND-Polygon abschirmen,
  verbunden am AGND-Pin des STM32

---

## Referenzen

- ABM8G Datenblatt, Abracon, Rev. 08.13.15
- STM32F411xC/xE Datenblatt DS10314, ST Microelectronics
- AN2867 "Oscillator design guide for STM32 microcontrollers", ST
- RM0383 STM32F411 Reference Manual

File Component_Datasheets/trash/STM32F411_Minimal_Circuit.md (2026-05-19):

# STM32F411RETx — Minimalbeschaltung (SWD)

> Quelle: DS10314 Rev 8, §3.13–3.15, §6.3.17, Figure 17, Table 56

---

## 1. Stromversorgung

| Pin | Kondensator | Hinweis |
|---|---|---|
| Jedes VDD/VSS-Paar | 100 nF + 1× 4,7 µF (gesamt) | Keramik, so nah wie möglich |
| VDDA / VSSA | 100 nF + 1 µF | Muss gleiches Potential wie VDD haben |
| **VCAP_1** (Pin 49) | **4,7 µF, ESR < 1 Ω** (X5R/X7R) | Ausgangspin des internen Reglers — **nicht weglassen** |

Betriebsspannung: **1,7 – 3,6 V** (für USB min. 3,0 V)

---

## 2. NRST

- Interner Pull-up: 30–50 kΩ (eingebaut)
- Externer Reset-IC **nicht nötig** — internes POR/BOR übernimmt das
- Empfohlen laut Datenblatt (Figure 32): **100 nF** nach GND (filtert parasitäre Resets)
- Optional: Reset-Taster (NO) zwischen NRST und GND

```
NRST ──[100 nF]── GND
NRST ──[Taster]── GND   (optional)
```

---

## 3. BOOT0

Bestimmt den Boot-Modus beim Reset:

| BOOT0-Pegel | Boot-Modus |
|---|---|
| LOW (GND) | Flash — normaler Betrieb |
| HIGH (VDD) | System Memory (UART/USB-Bootloader) |

```
BOOT0 ──[10 kΩ]── GND        ← normaler Betrieb
BOOT0 ──[Taster]── VDD        ← optional, für Bootloader-Zugang
```

> PDR_ON-Pin existiert beim LQFP64 **nicht** — interner Reset ist immer aktiv.

---

## 4. SWD (Serial Wire Debug)

| Signal | GPIO | LQFP64 Pin | SWD-Connector |
|---|---|---|---|
| SWDIO | PA13 | 46 | Pin 2 |
| SWCLK | PA14 | 37 | Pin 4 |
| SWO (optional) | PB3 | 39 | Pin 6 |
| NRST (optional) | NRST | 7 | Pin 10 |

Kein externer Pull-up/Pull-down auf SWD-Leitungen nötig — interne Beschaltung ausreichend.

**Standard 10-pin ARM Cortex Debug Connector (0,05" / 1,27 mm Raster):**

```
VCC  (1) (2) SWDIO
GND  (3) (4) SWCLK
GND  (5) (6) SWO
Key  (7) (8) NC
GND  (9) (10) NRST
```

---

## 5. Takt

- Interner HSI (16 MHz RC) reicht für Betrieb **ohne USB**
- Kein externer Quarz nötig für reine SWD-Programmierung
- Für USB: externer HSE-Quarz zwingend erforderlich (→ USB-Notes)

---

## 6. Minimale Pinliste (LQFP64)

Alle Pins die zwingend verdrahtet werden müssen:

| Pin | Name | Anschluss |
|---|---|---|
| 1, 19, 28, 50, 75 | VDD | 3,3 V |
| 18, 27, 49, 74 | VSS | GND |
| 32 | VDDA | 3,3 V |
| 20 | VSSA | GND |
| 49 | VCAP_1 | 4,7 µF → GND |
| 7 | NRST | 100 nF → GND |
| 60 | BOOT0 | 10 kΩ → GND |
| 46 | PA13 / SWDIO | Debugger |
| 37 | PA14 / SWCLK | Debugger |

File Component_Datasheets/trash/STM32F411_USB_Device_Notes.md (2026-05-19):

# STM32F411RETx — USB Full-Speed Device: Hardware Notes

> **Sources:** STM32F411xC/xE Datasheet DS10314 Rev 8 (Jan 2024) · ST AN4879 (USB hardware & PCB guidelines) · USB Type-C Spec Rev 2.0 · ST Community / Hackaday / web cross-check.

---

## 1. USB Peripheral Overview

The STM32F411RE embeds a **USB OTG Full-Speed (OTG_FS)** peripheral with an **on-chip PHY (transceiver)** — no external USB transceiver IC is required.

| Feature | Value |
|---|---|
| Standard | USB 2.0 Full-Speed (12 Mbit/s), OTG 1.0 |
| PHY | On-chip integrated — no external component |
| Endpoints | 4 bidirectional |
| FIFO | 320 × 35 bit, dynamically configurable |
| Suspend / Resume | Supported |
| D+ pull-up | Internal ≈ 1.5–2.1 kΩ, software-controlled |
| D± pull-down | Internal ≈ 17–24 kΩ, hardware-controlled |
| Required clock | **48 MHz from PLL — HSE crystal mandatory** |

> **Datasheet §3.27:** *"HNP/SNP/IP inside (no need for any external resistor)"* — the internal D+ pull-up for Full-Speed device enumeration is built into the chip. **No external 1.5 kΩ pull-up on D+ is needed.**

---

## 2. MCU Pin Connections

All USB signals use **Alternate Function 10 (AF10 = OTG1_FS)**.

| Signal | GPIO | LQFP64 pin | Direction | Notes |
|---|---|---|---|---|
| USB_FS_DM | PA11 | 44 | Bidir. | D− data line |
| USB_FS_DP | PA12 | 45 | Bidir. | D+ data line |
| OTG_FS_VBUS | PA9 | 42 | Input | VBUS sense — see §5 |
| USB_FS_ID | PA10 | 43 | Input | OTG ID pin — leave unconnected for device-only |
| USB_FS_SOF | PA8 | 41 | Output | Optional: Start-of-Frame pulse |

> For **device-only** operation leave PA10 (USB_FS_ID) **unconnected**. The OTG controller treats an open/high ID pin as device mode.

---

## 3. External Components

### 3.1 USB Data Lines — Series Resistors (optional)

**Per ST AN4879:** *"The matching output impedance is already embedded in the pad transceiver and in line with the USB specification."* — external series resistors on D+/D− are **not required** on the STM32F411.

However, 22 Ω series resistors are still commonly added on compact boards as an extra EMI precaution, especially when USB traces exceed 30–40 mm. They will not harm the design if added.

| Component | Value | Status |
|---|---|---|
| R_DM (PA11, D−) | 22 Ω | Optional — EMI damping only |
| R_DP (PA12, D+) | 22 Ω | Optional — EMI damping only |

> **Do not add an external 1.5 kΩ pull-up on D+.** The internal pull-up is calibrated; an extra parallel resistor lowers the combined value and can break enumeration.

### 3.2 ESD Protection (strongly recommended)

Place as close as possible to the USB connector.

| Component | Suggested Part | Protects |
|---|---|---|
| D+/D− ESD clamp | USBLC6-2SC6 (SOT-23-6) | D+, D− signal lines |
| VBUS TVS diode | ESDA7P60-1U1M or SMBJ5.0A | VBUS overvoltage |

The USBLC6-2SC6 is a rail-to-rail steering clamp — it handles IEC 61000-4-2 Level 4 ESD events on both data lines with very low capacitance (~1 pF) so it does not distort the USB signal.

### 3.3 Crystal / HSE Oscillator — **Mandatory for USB**

The USB clock must be **exactly 48 MHz**, derived from the PLL locked to the external crystal. The internal HSI RC oscillator is not stable enough (USB 2.0 requires ≤ 500 ppm clock accuracy; the HSI is ±1%).

| Component | Typical Value | Notes |
|---|---|---|
| HSE crystal | 8 MHz or 12 MHz | Both easily produce 48 MHz via PLL |
| Crystal load capacitors | 2 × 18–22 pF | Match crystal C_L spec exactly |
| Series resistor (optional) | 0–470 Ω | Only if crystal datasheet recommends it |

**PLL example — 8 MHz HSE → 48 MHz USB clock:**
```
PLLM=4, PLLN=192, PLLP=2  →  SYSCLK = 96 MHz
PLLQ=4                     →  USB clock = (192/4) × (8/4) = 48 MHz ✓
```
CubeMX calculates this automatically when USB_OTG_FS is enabled.

### 3.4 Power Supply Decoupling

Required per datasheet Figure 17 (§6.1.6):

| Pin(s) | Capacitor | Notes |
|---|---|---|
| Each VDD / VSS pair | 100 nF ceramic + one 4.7 µF ceramic on board | Place as close to pins as possible |
| VCAP_1 (pin 49) | **2.2–4.7 µF**, ESR < 1 Ω (X5R/X7R) | Internal regulator output — **must not be omitted** |
| VDDA / VSSA | 1 µF + 100 nF ceramic | Analog supply |

> The LQFP64 has **one VCAP pin** only. Use a single 4.7 µF (preferred) or 2.2 µF low-ESR ceramic. Do **not** connect VCAP to VDD — it is the regulator's output, not an input.

### 3.5 VBUS Power Supply

For a **bus-powered device** (board powered from USB host):

```
USB-C VBUS (5 V)
    │
    ├── [Ferrite bead, e.g. Murata BLM21AG121SN1D, 120 Ω @ 100 MHz]
    │       └── 2.2 µF ceramic to GND  (VBUS filtering, near connector)
    │
    └── [3.3 V LDO, e.g. AMS1117-3.3 or LD39015]
            ├── 10 µF + 100 nF ceramic on output
            └── → VDD, VDDA of STM32
```

- LDO must be rated ≥ 500 mA (USB 2.0 high-power device limit)
- Total VBUS capacitance (including LDO input cap) should stay **below 4.7 µF** to avoid triggering the host's short-circuit detection during hot-plug

---

## 4. USB Electrical Specifications (Datasheet Table 63)

| Symbol | Parameter | Min | Typ | Max | Unit |
|---|---|---|---|---|---|
| V_DD | USB OTG FS operating voltage | — | 3.0 | 3.6 | V |
| R_PD (DM/DP) | Internal pull-down on PA11/PA12 | 17 | 21 | 24 | kΩ |
| R_PU (DM/DP) | Internal D+ pull-up on PA12 | 1.5 | 1.8 | 2.1 | kΩ |
| V_OL | Output low (R_L = 1.5 kΩ to 3.6 V) | — | — | 0.3 | V |
| V_OH | Output high (R_L = 15 kΩ to GND) | 2.8 | — | 3.6 | V |
| t_STARTUP | PHY startup time | — | — | 1 | µs |
| t_r / t_f | Rise / fall time (C_L = 50 pF) | 4 | — | 20 | ns |

> Full USB FS specs guaranteed at VDD ≥ 3.0 V. Functional down to 2.7 V but D+/D− characteristics are degraded between 2.7–3.0 V (DS Table 15, note 6).

---

## 5. VBUS Sensing (PA9)

PA9 is an **FT-type (5 V-tolerant) GPIO**. Its absolute maximum input is VDD + 4.0 V, so at VDD = 3.3 V the limit is 7.3 V — 5 V is safe when the MCU is powered.

**Problem with direct connection:** When the MCU is unpowered (VDD = 0 V) and VBUS = 5 V is present, the limit drops to 0 + 4.0 = 4.0 V — meaning 5 V directly on PA9 violates the absolute maximum rating.

### Recommended: Resistor divider (safe in all states)

```
VBUS (5 V) ──[4.7 kΩ]──┬── PA9 (floating input, no pull)
                        │
                      [10 kΩ]
                        │
                        GND
```

- MCU powered (VDD = 3.3 V), VBUS = 5 V: V_PA9 ≈ 3.4 V — detects HIGH ✓, well below 7.3 V limit ✓
- MCU unpowered (VDD = 0 V), VBUS = 5 V: V_PA9 ≈ 3.4 V — safely below 4.0 V limit ✓

> **Datasheet Table 63 Note:** *"When VBUS sensing feature is enabled, PA9 should be left at their default state (floating input), not as alternate function."*

### Alternative: Disable VBUS sensing entirely

If the board is always bus-powered, you can skip the PA9 connection entirely and set `OTG_GCCFG_NOVBUSSENS = 1` in firmware (or the equivalent HAL setting). The device enumerates as soon as it powers up.

---

## 6. USB Type-C Connector — CC1, CC2, SBU1, SBU2

### 6.1 CC1 and CC2 — Required Rd Termination

CC pins carry the Configuration Channel signal. A host (DFP) applies a pull-up (Rp) to each CC pin. When it detects a pull-down (Rd) on a CC pin it knows a device is connected and enables VBUS.

**For a device with no Power Delivery:**

| Pin | Connection | Component |
|---|---|---|
| CC1 | **5.1 kΩ → GND** | 5.1 kΩ ±10 %, 1/16 W |
| CC2 | **5.1 kΩ → GND** | 5.1 kΩ ±10 %, 1/16 W |

The 5.1 kΩ value is the **Rd** resistance defined in USB Type-C Spec Table 4-36.

**Why both CC pins need independent resistors:**
1. USB-C is reversible — the cable can be plugged in either orientation
2. The host detects cable orientation by which CC pin sees the Rd pull-down
3. The 5.1 kΩ also signals to the host how much current the device wants (5.1 kΩ = default USB current, up to 900 mA)

> **Critical:** Do **not** share one resistor by connecting CC1 to CC2 and using a single pull-down. If an e-marked (active) cable is used, its internal Ra resistor (~1 kΩ) appears in parallel, reducing the combined resistance below the spec threshold, and some hosts will not recognise the device. The Raspberry Pi 4 had exactly this bug in its first revision.

Without the 5.1 kΩ Rd resistors, the host will never enable VBUS and the device will not power up.

> To add USB Power Delivery later: replace both 5.1 kΩ resistors with a PD controller IC (e.g. FUSB302, STUSB4500) connected to CC1 and CC2.

### 6.2 SBU1 and SBU2 — Leave Unconnected

SBU (Sideband Use) pins are only used for alternate modes (DisplayPort, Thunderbolt, UART accessories). For a plain USB 2.0 device:

| Pin | Treatment |
|---|---|
| SBU1 (A8) | Leave **unconnected** |
| SBU2 (B8) | Leave **unconnected** |

---

## 7. USB Type-C Receptacle — Complete Pin Summary

| USB-C Pin(s) | Signal | Connection |
|---|---|---|
| A1, B12 | GND | Board GND |
| A4, B9 | VBUS | 5 V rail → ferrite → LDO |
| A5 | CC1 | 5.1 kΩ → GND |
| B5 | CC2 | 5.1 kΩ → GND |
| A6, B6 | D+ | Tie together → (22 Ω opt.) → PA12 |
| A7, B7 | D− | Tie together → (22 Ω opt.) → PA11 |
| A8 | SBU1 | Leave unconnected |
| B8 | SBU2 | Leave unconnected |
| A2, A3, B10, B11 | TX±/RX± | Leave unconnected (USB 3.x SuperSpeed, not used) |

> **Both D+ pins (A6, B6) and both D− pins (A7, B7) must be tied together.** USB 2.0 differential pairs appear on both sides of the connector — which side is active depends on cable orientation. Shorting each pair together ensures the device works regardless of how the cable is inserted.

---

## 8. Schematic Checklist

```
STM32F411RE (LQFP64)                USB-C Receptacle
                                  ┌──────────────────┐
VDD 3.3V ◄─ LDO ◄─ [Ferrite] ◄── VBUS A4/B9 (5 V)  │
                                  │                  │
                            [2.2 µF to GND near conn.]
                                  │                  │
PA11 ──[22 Ω, opt.]────────────── D− A7+B7          │
PA12 ──[22 Ω, opt.]────────────── D+ A6+B6          │
                                  │                  │
           USBLC6-2SC6 ─── between D+, D−, and GND  │ ← ESD
           SMBJ5.0A    ─── VBUS to GND               │ ← TVS
                                  │                  │
PA9 ──[4.7 kΩ]──┬── (sense)       │                  │
               [10 kΩ]           │                  │
                │                │                  │
               GND ──────────── GND A1/B12          │
                                  │                  │
GND ──[5.1 kΩ]────────────────── CC1 A5             │
GND ──[5.1 kΩ]────────────────── CC2 B5             │
                                  │                  │
          (unconnected) ───────── SBU1 A8            │
          (unconnected) ───────── SBU2 B8            │
                                  └──────────────────┘

VCAP_1 (pin 49) ──[4.7 µF, ESR < 1 Ω, X5R]── GND
VDDA (pin 32)   ──[1 µF + 100 nF]──────────── GND
Each VDD pin    ──[100 nF + one 4.7 µF total]─ GND

HSE Crystal ── OSC_IN (PH0 or pin 5) / OSC_OUT (PH1 or pin 6)
  Each crystal pin ── [18–22 pF ceramic] ── GND
```

---

## 9. Firmware / CubeMX Setup

1. **Enable USB_OTG_FS** in Device mode
2. **Clock tree:** Set HSE as PLL source; configure PLLQ to output 48 MHz for USB
3. **PA9:** Leave as floating input (no pull), or disable VBUS sensing with `OTG_GCCFG_NOVBUSSENS = 1`
4. **PA10 (ID):** Leave unconfigured / as floating input — the peripheral reads it HIGH = device mode
5. **USB middleware:** STM32 USB Device Library (CDC, HID, MSC, etc.) via CubeMX middleware tab

---

## 10. Common Mistakes

| Mistake | Consequence |
|---|---|
| Forgetting 5.1 kΩ on CC1 / CC2 | Host never enables VBUS — device has no power |
| Sharing one resistor between CC1 and CC2 | Fails with e-marked cables (Raspberry Pi 4 bug) |
| Using HSI instead of HSE for USB clock | Intermittent disconnects and failed enumeration |
| Connecting VBUS directly to PA9 when MCU is unpowered | PA9 absolute max exceeded (5 V > VDD+4 V = 4 V) |
| Omitting VCAP_1 capacitor | Internal regulator unstable — unpredictable MCU behaviour |
| Not tying both D+/D− pairs of USB-C together | Device only enumerates in one cable orientation |
| Adding external 1.5 kΩ D+ pull-up | Lowers combined resistance → enumeration failure |
| VBUS capacitance > 4.7 µF total | Host short-circuit protection may trip on hot-plug |

---

## 11. References

- STM32F411xC/xE Datasheet DS10314 Rev 8 (Jan 2024) — §3.27, Table 63, Figure 17
- ST AN4879 — *Introduction to USB hardware and PCB guidelines using STM32 MCUs*
- USB Type-C Specification Rev 2.0 — Table 4-36 (Rd/Rp/Ra values)
- ST RM0383 — STM32F411 Reference Manual (OTG_FS registers)
- [Hackaday — All About USB-C: Resistors and Emarkers](https://hackaday.com/2023/01/04/all-about-usb-c-resistors-and-emarkers/)
- ST Community — Management of VBUS sensing for USB device design

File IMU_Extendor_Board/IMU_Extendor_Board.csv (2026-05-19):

Id | Designator | Footprint | Quantity | Designation | Supplier and ref
1X | C102,C101 | C_0805_2012Metric_Pad1.18x1.45mm_HandSolder | 2 | 1u
2X | C208 | C_0603_1608Metric_Pad1.08x0.95mm_HandSolder | 1 | 1u
3X | C206,C214 | C_0603_1608Metric_Pad1.08x0.95mm_HandSolder | 2 | 4u7
4X | Y501,Y401,Y203 | Oscillator_SMD_ECS_2520MV-xxx-xx-4Pin_2.5x2.0mm | 3 | ECS-327KE
5X | C502 | C_0603_1608Metric | 1 | 2.2u
6X | C211,C210 | 0402_1005Metric_Pad0.74x0.62mm_HandSolder | 2 | 27p
7X | U201 | LQFP-64_10x10mm_P0.5mm | 1 | STM32F722RETx
8X | R205,R202,R410,R409,R407,R201,R408 | 0402_1005Metric_Pad0.74x0.62mm_HandSolder | 7 | 10k
9X | C209X,C503X,C205X,C401X,C207X,C202X,C203X,C201X,C403X,C204X,C402X | 0402_1005Metric_Pad0.74x0.62mm_HandSolder | 11 | 100n
10 | U102 | SOT-23-6 | 1 | USBLC6-2SC6
11X | R402,R601,R405,R406,R502,R203,R603,R403,R505,R501,R602,R503 | 0402_1005Metric_Pad0.74x0.62mm_HandSolder | 12 | 0R
12X | R103,R207 | 0402_1005Metric_Pad0.74x0.62mm_HandSolder | 2 | 1k
13 | D101,D201 | LED_0603_1608Metric | 2 | LED
14 | U101 | SOT-89-5_Handsoldering | 1 | XC6210B332PR-G
15X | R504,R404,R206,R506,R401 | 0402_1005Metric_Pad0.74x0.62mm_HandSolder | 5 | DNP
16X | C501,C504,C404,C212 | 0402_1005Metric_Pad0.74x0.62mm_HandSolder | 4 | 10n
17X | R204 | 0402_1005Metric_Pad0.74x0.62mm_HandSolder | 1 | 4k7
18X | J601 | PinHeader_1x07_P2.54mm_Vertical | 1 | Conn_01x07_Pin
19X | R102,R101 | 0402_1005Metric_Pad0.74x0.62mm_HandSolder | 2 | 5k1
20X | J101 | USB_C_Receptacle_GCT_USB4105-xx-A_16P_TopMnt_Horizontal | 1 | USB_C_Receptacle_USB2.0_16P
21X | C213 | C_0603_1608Metric_Pad1.08x0.95mm_HandSolder | 1 | DNP
22X | J501 | PinHeader_1x06_P2.54mm_Vertical | 1 | Conn_01x06_Pin
23X | Y202 | Crystal_SMD_Abracon_ABM8G-4Pin_3.2x2.5mm | 1 | Crystal |  | #Falsche FOOTPRINT PIN 1 ist Falsch
24X | U401 | BNO086 | 1 | BNO086
25X | J703 | PinHeader_1x04_P2.54mm_Vertical | 1 | Conn_01x04_Pin
26X | R208 | 0402_1005Metric_Pad0.74x0.62mm_HandSolder | 1 | 0.1R
27 | U501 | ICM-42688-p | 1 | ICM-42688-P
28X | J201 | R_0805_2012Metric_Pad1.20x1.40mm_HandSolder | 1 | DNP
29X | J702 | PinHeader_1x10_P1.27mm_Vertical_SMD_Pin1Right | 1 | Conn_01x10_Pin

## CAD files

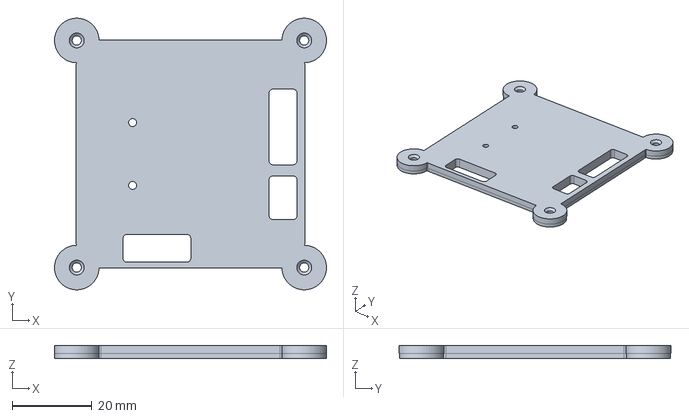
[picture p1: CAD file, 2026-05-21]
enclosure/enclosure_lid.step
68.3 x 68.2 x 3.15 mm

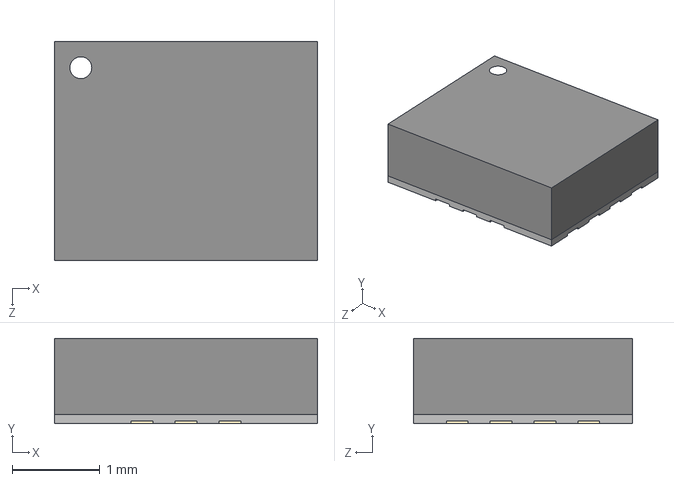
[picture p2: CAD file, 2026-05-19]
IMU_Extendor_Board/Component_Lib/IMUs/ICM-42688-P.step
3.00 x 0.97 x 2.50 mm

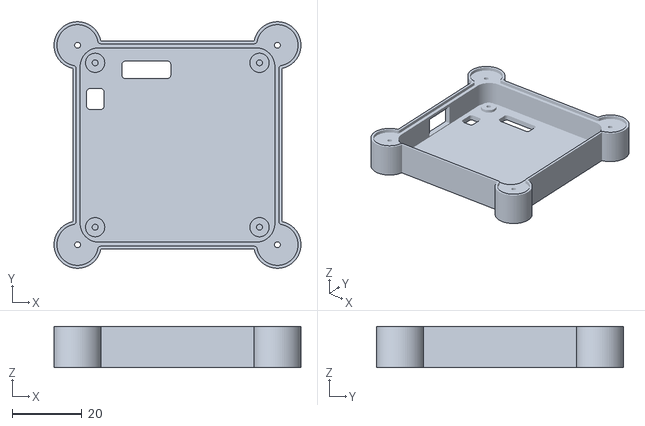
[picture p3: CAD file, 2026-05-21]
enclosure/enclosure_bottom.stl
70.6 x 70.5 x 11.8

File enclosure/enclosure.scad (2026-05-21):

// IMU Extendor Board enclosure
// Bottom tray + lid with M2 self-tapping screws (washers recommended; PCB holes are 2.7mm)
// PCB outline: ~55x55 mm rounded rectangle, mounting holes at 47x47 mm grid

// --- Parameters ---
pcb_x      = 26.097;   // PCB outline min X (from kicad_pcb)
pcb_y      = 27.097;   // PCB outline min Y
pcb_w      = 81.0 - 26.097;   // ~54.9
pcb_h      = 81.903 - 27.097; // ~54.8
pcb_r      = 5.0;      // corner radius
pcb_thk    = 1.6;

// Mounting holes in board coords (from kicad_pcb)
holes      = [[30,31],[77,31],[77,78],[30,78]];

wall       = 2.0;      // outer wall thickness
floor_thk  = 2.0;      // bottom plate thickness
lid_thk    = 2.0;      // lid plate thickness
gap        = 0.4;      // clearance between PCB edge and inner wall
standoff_h = 1.0;      // floor-top to PCB-bottom
clear_top  = 7.2;      // PCB-top to lid-inner; keeps USB-C cutout vertically centered in wall

post_od    = 5.5;      // standoff/screw post outer diameter
pilot_d    = 1.7;      // M2 self-tap pilot hole diameter
lid_clear  = 2.3;      // lid screw clearance hole (M2 loose)
pcb_pilot_bottom_skin = 0.4; // leave this much material under PCB screw pilot holes

// Lid drops into a rebate so it self-aligns
rebate_depth = 1.2;
rebate_clear = 0.3;

$fn = 64;

// Inner cavity footprint (PCB + gap)
inner_x = pcb_x - gap;
inner_y = pcb_y - gap;
inner_w = pcb_w + 2*gap;
inner_h = pcb_h + 2*gap;
inner_r = pcb_r + gap;

// Outer shell footprint
outer_x = inner_x - wall;
outer_y = inner_y - wall;
outer_w = inner_w + 2*wall;
outer_h = inner_h + 2*wall;
outer_r = inner_r + wall;
box_cx = pcb_x + pcb_w/2;
box_cy = pcb_y + pcb_h/2;

function mirror_y(y) = 2*box_cy - y;

// Total inner height (floor inner to lid-rebate level)
post_total = standoff_h + pcb_thk + clear_top;

// --- Lid-attachment "ears" at outer corners ---
// Each ear is a vertical cylinder overlapping the outer wall corner
// to provide material for an M2 self-tap pilot for the lid screw.
ear_od     = 5.5;     // OD of corner ear (matches PCB standoff)
ear_bulge  = 4.0;     // diagonal outward offset so ear clears the PCB standoffs.
                      // PCB holes sit 4mm from PCB corner; with this bulge the ear
                      // ends up ~1.5mm clear of the PCB standoff.

// Outer/inner corner-arc center (shared)
corner_cx = [pcb_x + pcb_r, pcb_x + pcb_w - pcb_r, pcb_x + pcb_w - pcb_r, pcb_x + pcb_r];
corner_cy = [pcb_y + pcb_r, pcb_y + pcb_r,         pcb_y + pcb_h - pcb_r, pcb_y + pcb_h - pcb_r];
corner_dx = [-1,  1,  1, -1] / sqrt(2);
corner_dy = [-1, -1,  1,  1] / sqrt(2);

// Place ear center so it just bulges past the original outer arc (outer_r) by ear_bulge,
// with ear_od/2 of the ear extending outward.
ear_radial = outer_r + ear_bulge - ear_od/2;
ear_positions = [
    for (i = [0:3]) [corner_cx[i] + corner_dx[i]*ear_radial,
                     corner_cy[i] + corner_dy[i]*ear_radial]
];

// --- Lid cutouts: [center_x, center_y, width_x, width_y] in PCB coords ---
// All connectors are on F.Cu (top of PCB) and accessed through the lid.
// Sized from actual pad bounding boxes + ~3mm margin for connector body / cable.
swd_uart_shift = 11.5; // move SWD opening toward the UART header

lid_cutouts = [
    // SWD J501 (1x6 vertical, top edge): pads X=27.27..39.97, Y=78.19
    [33.62 + swd_uart_shift, 78.19, 17.0, 7.0],
    // Optical Flow J601 (1x7 vertical, right edge): pads X=76.8, Y=40.1..55.3
    [76.8,   47.71,  7.0, 19.0],
    // UART J703 (1x4 vertical, right edge): pads X=76.8, Y=61.7..69.3
    [76.8,   65.49,  7.0, 11.0],
];

// --- Floor cutouts: same format, cut through the case floor ---
// J702 (1x10 1.27mm, mounted on B.Cu): connector body is on PCB underside,
// cable mates from below -> cut floor under it. Pads X=38.9..50.4, Y=31.5..34.5
// J102 (1x2 power, F.Cu) accessed from below per request.
//   Pads X=30.06, Y=40.08..42.62
floor_cutouts = [
    [44.635, mirror_y(33.0),   14.0, 5.0],   // J702 GPIO breakout (B.Cu: Y mirrored about box centre)
    [30.06,  mirror_y(41.35),   5.0, 6.0],   // J102 5V power     (B.Cu: Y mirrored about box centre)
];

// User LEDs (small viewing holes in lid)
led_positions = [[39, 62.4], [39, 46.6]];
led_hole_d    = 2.0;

// --- Side cutouts in BOTTOM walls ---
// PCB top in outer Z coords: floor_thk + standoff_h + pcb_thk
pcb_top_z = floor_thk + standoff_h + pcb_thk;

// Side openings: [edge, along_axis_center, width_along_edge, z_center, z_height]
//   edge: "xmin"/"xmax"/"ymin"/"ymax" -- which wall to cut through
// USB-C J101 at (29.75, 54.5), rot=-90 -- receptacle mouth faces -X (xmin wall)
//   Mouth centerline ~1.3mm above PCB top => z_center = pcb_top_z + 1.3
//   Generous cutout for plug overmold: 12mm wide along Y, 7mm tall along Z
side_cutouts = [
    ["xmin", 54.5, 12.0, pcb_top_z + 1.3, 7.0],   // USB-C J101
];

module rrect(x, y, w, h, r) {
    translate([x, y])
        hull() {
            translate([r, r])       circle(r=r);
            translate([w-r, r])     circle(r=r);
            translate([r, h-r])     circle(r=r);
            translate([w-r, h-r])   circle(r=r);
        }
}

// Outline shared by bottom outer shell and lid: rounded rect + bulged corner ears
module shell_outline_2d() {
    union() {
        rrect(outer_x, outer_y, outer_w, outer_h, outer_r);
        for (p = ear_positions)
            translate([p[0], p[1]]) circle(d=ear_od + 2*ear_bulge);
    }
}

// --- BOTTOM ---
module bottom() {
    pilot_depth = standoff_h + 1;
    ear_h = floor_thk + post_total - rebate_depth;

    difference() {
        union() {
            // Outer shell
            linear_extrude(floor_thk + post_total)
                shell_outline_2d();
            // Corner ear bosses (flush with rebate floor).
            // Kept inside the main difference so the pilot hole below punches through
            // both the boss AND the surrounding shell material at the ear positions.
            for (p = ear_positions)
                translate([p[0], p[1], 0])
                    cylinder(d=ear_od, h=ear_h);
        }

        // Hollow inside (leave floor)
        translate([0,0,floor_thk])
            linear_extrude(post_total + 1)
                rrect(inner_x, inner_y, inner_w, inner_h, inner_r);

        // Lid rebate
        translate([0,0,floor_thk + post_total - rebate_depth])
            linear_extrude(rebate_depth + 0.1)
                offset(r=-wall/2 + rebate_clear/2)
                    shell_outline_2d();

        // Corner ear pilot holes — full depth through ear so any screw length works
        for (p = ear_positions)
            translate([p[0], p[1], -0.1])
                cylinder(d=pilot_d, h=ear_h + 0.2);

        // PCB mounting screw pilots continue into the floor, leaving a thin bottom skin.
        for (h = holes)
            translate([h[0], h[1], pcb_pilot_bottom_skin])
                cylinder(d=pilot_d, h=floor_thk - pcb_pilot_bottom_skin + 0.2);

        // Floor cutouts
        for (c = floor_cutouts)
            translate([c[0] - c[2]/2, c[1] - c[3]/2, -1])
                linear_extrude(floor_thk + 2)
                    offset(r=1, $fn=24)
                        offset(r=-1)
                            square([c[2], c[3]], center=false);

        // Side wall cutouts
        for (s = side_cutouts) {
            edge = s[0]; ctr = s[1]; w = s[2]; zc = s[3]; zh = s[4];
            cut_depth = wall + 2;
            if (edge == "xmin")
                translate([outer_x - 1, ctr - w/2, zc - zh/2])
                    cube([cut_depth, w, zh]);
            else if (edge == "xmax")
                translate([outer_x + outer_w - wall - 1, ctr - w/2, zc - zh/2])
                    cube([cut_depth, w, zh]);
            else if (edge == "ymin")
                translate([ctr - w/2, outer_y - 1, zc - zh/2])
                    cube([w, cut_depth, zh]);
            else if (edge == "ymax")
                translate([ctr - w/2, outer_y + outer_h - wall - 1, zc - zh/2])
                    cube([w, cut_depth, zh]);
        }
    }

    // PCB standoffs — added outside the main difference so the inner-cavity cut
    // doesn't eat them. They sit inside the hollow, so no shell material to worry about.
    for (h = holes) {
        translate([h[0], h[1], floor_thk])
            difference() {
                cylinder(d=post_od, h=standoff_h);
                translate([0,0,standoff_h - pilot_depth + 0.1])
                    cylinder(d=pilot_d, h=pilot_depth);
            }
    }
}
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

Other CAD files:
enclosure/enclosure_lid.stl

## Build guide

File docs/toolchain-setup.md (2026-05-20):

# Toolchain Setup

Fresh-machine setup for building, flashing, and debugging the calibration board firmware on Linux (Ubuntu/Debian-based). For day-to-day workflow see `firmware.md`.

## 1. Compiler + build tools

**Option A — native (apt):**

```bash
sudo apt install gcc-arm-none-eabi cmake ninja-build
```

**Option B — Docker (skip this step entirely):** if you have Docker installed, use `Firmware/scripts/build-docker.sh` and you don't need any of the above on the host. The first invocation builds a `debian:trixie-slim` image with the C toolchain baked in (~400 MB, ~2 min one-time cost). See `firmware.md` for details. **You still need steps 2–4** for flashing — Docker only solves the build side.

Verify:

```bash
arm-none-eabi-gcc --version    # expect 14.x
cmake --version                 # expect 3.22+
```

## 2. STM32CubeCLT

The flash/debug stack (`STM32_Programmer_CLI` + `ST-LINK_gdbserver`) ships as part of STM32CubeCLT. **Not in apt** — download manually:

1. Get the Linux `.deb` bundle from https://www.st.com/en/development-tools/stm32cubeclt.html (requires free ST account).
2. Unpack and install:
   ```bash
   unzip st-stm32cubeclt_*_amd64.deb_bundle.sh.zip
   chmod +x st-stm32cubeclt_*_amd64.deb_bundle.sh
   ./st-stm32cubeclt_*_amd64.deb_bundle.sh --target /tmp/clt --noexec --quiet --noprogress
   sudo apt-get install -y \
     /tmp/clt/st-stlink-server-*.deb \
     /tmp/clt/st-stlink-udev-rules-*.deb \
     /tmp/clt/st-stm32cubeclt-*.deb
   ```
   Accept the default install path `/opt/st/stm32cubeclt_1.21.0/` — the helper scripts and CLion debug-server config assume it.

## 3. System-wide ST tool symlinks

The helper scripts and any AI agent expect `STM32_Programmer_CLI` / `ST-LINK_gdbserver` on `PATH`. Symlinks in `/usr/local/bin/` work for all shell types (including non-login shells):

```bash
sudo ln -sf /opt/st/stm32cubeclt_1.21.0/STM32CubeProgrammer/bin/STM32_Programmer_CLI /usr/local/bin/
sudo ln -sf /opt/st/stm32cubeclt_1.21.0/STLink-gdb-server/bin/ST-LINK_gdbserver /usr/local/bin/
```

Verify from a new shell in `/tmp`:

```bash
STM32_Programmer_CLI --version
ST-LINK_gdbserver --help
```

## 4. ST-LINK permissions

The `st-stlink-udev-rules` package installs `/etc/udev/rules.d/49-stlinkv*.rules` granting `plugdev` group access. Add yourself if needed:

```bash
sudo usermod -aG plugdev "$USER"
# log out and back in for group change to take effect
```

If you see `libusb: error [get_usbfs_fd] libusb requires write access to USB device nodes`:

```bash
sudo udevadm control --reload-rules && sudo udevadm trigger
# unplug and re-plug the ST-LINK
```

## 5. Smoke test

ST-LINK plugged in, target board powered:

```bash
STM32_Programmer_CLI -l st-link             # should list probe + serial
STM32_Programmer_CLI -c port=SWD -r32 0x08000000 4   # reads first 4 bytes of flash
```

Expected target ID: **0x452** (STM32F72x/F73x family). If you get `Error: No STM32 target found`, check SWD wiring (SWCLK→PA14, SWDIO→PA13, GND, 3V3 ref) and that target voltage reads ~3.3 V.

## 6. Build + flash test

```bash
Firmware/scripts/flash.sh
```

Should report `Download verified successfully` and `Application is running`. If yes — setup is complete; see `firmware.md` for workflow.

## CLion users (optional)

CLion picks up `.idea/debugServers/ST_LINK.xml` automatically — it already points at the installed CubeCLT paths. In **Settings → Toolchains** set:

- C compiler: `/usr/bin/arm-none-eabi-gcc`
- C++ compiler: `/usr/bin/arm-none-eabi-g++`
- Debugger: `/opt/st/stm32cubeclt_1.21.0/GNU-tools-for-STM32/bin/arm-none-eabi-gdb`

For run-configs see `firmware.md`.

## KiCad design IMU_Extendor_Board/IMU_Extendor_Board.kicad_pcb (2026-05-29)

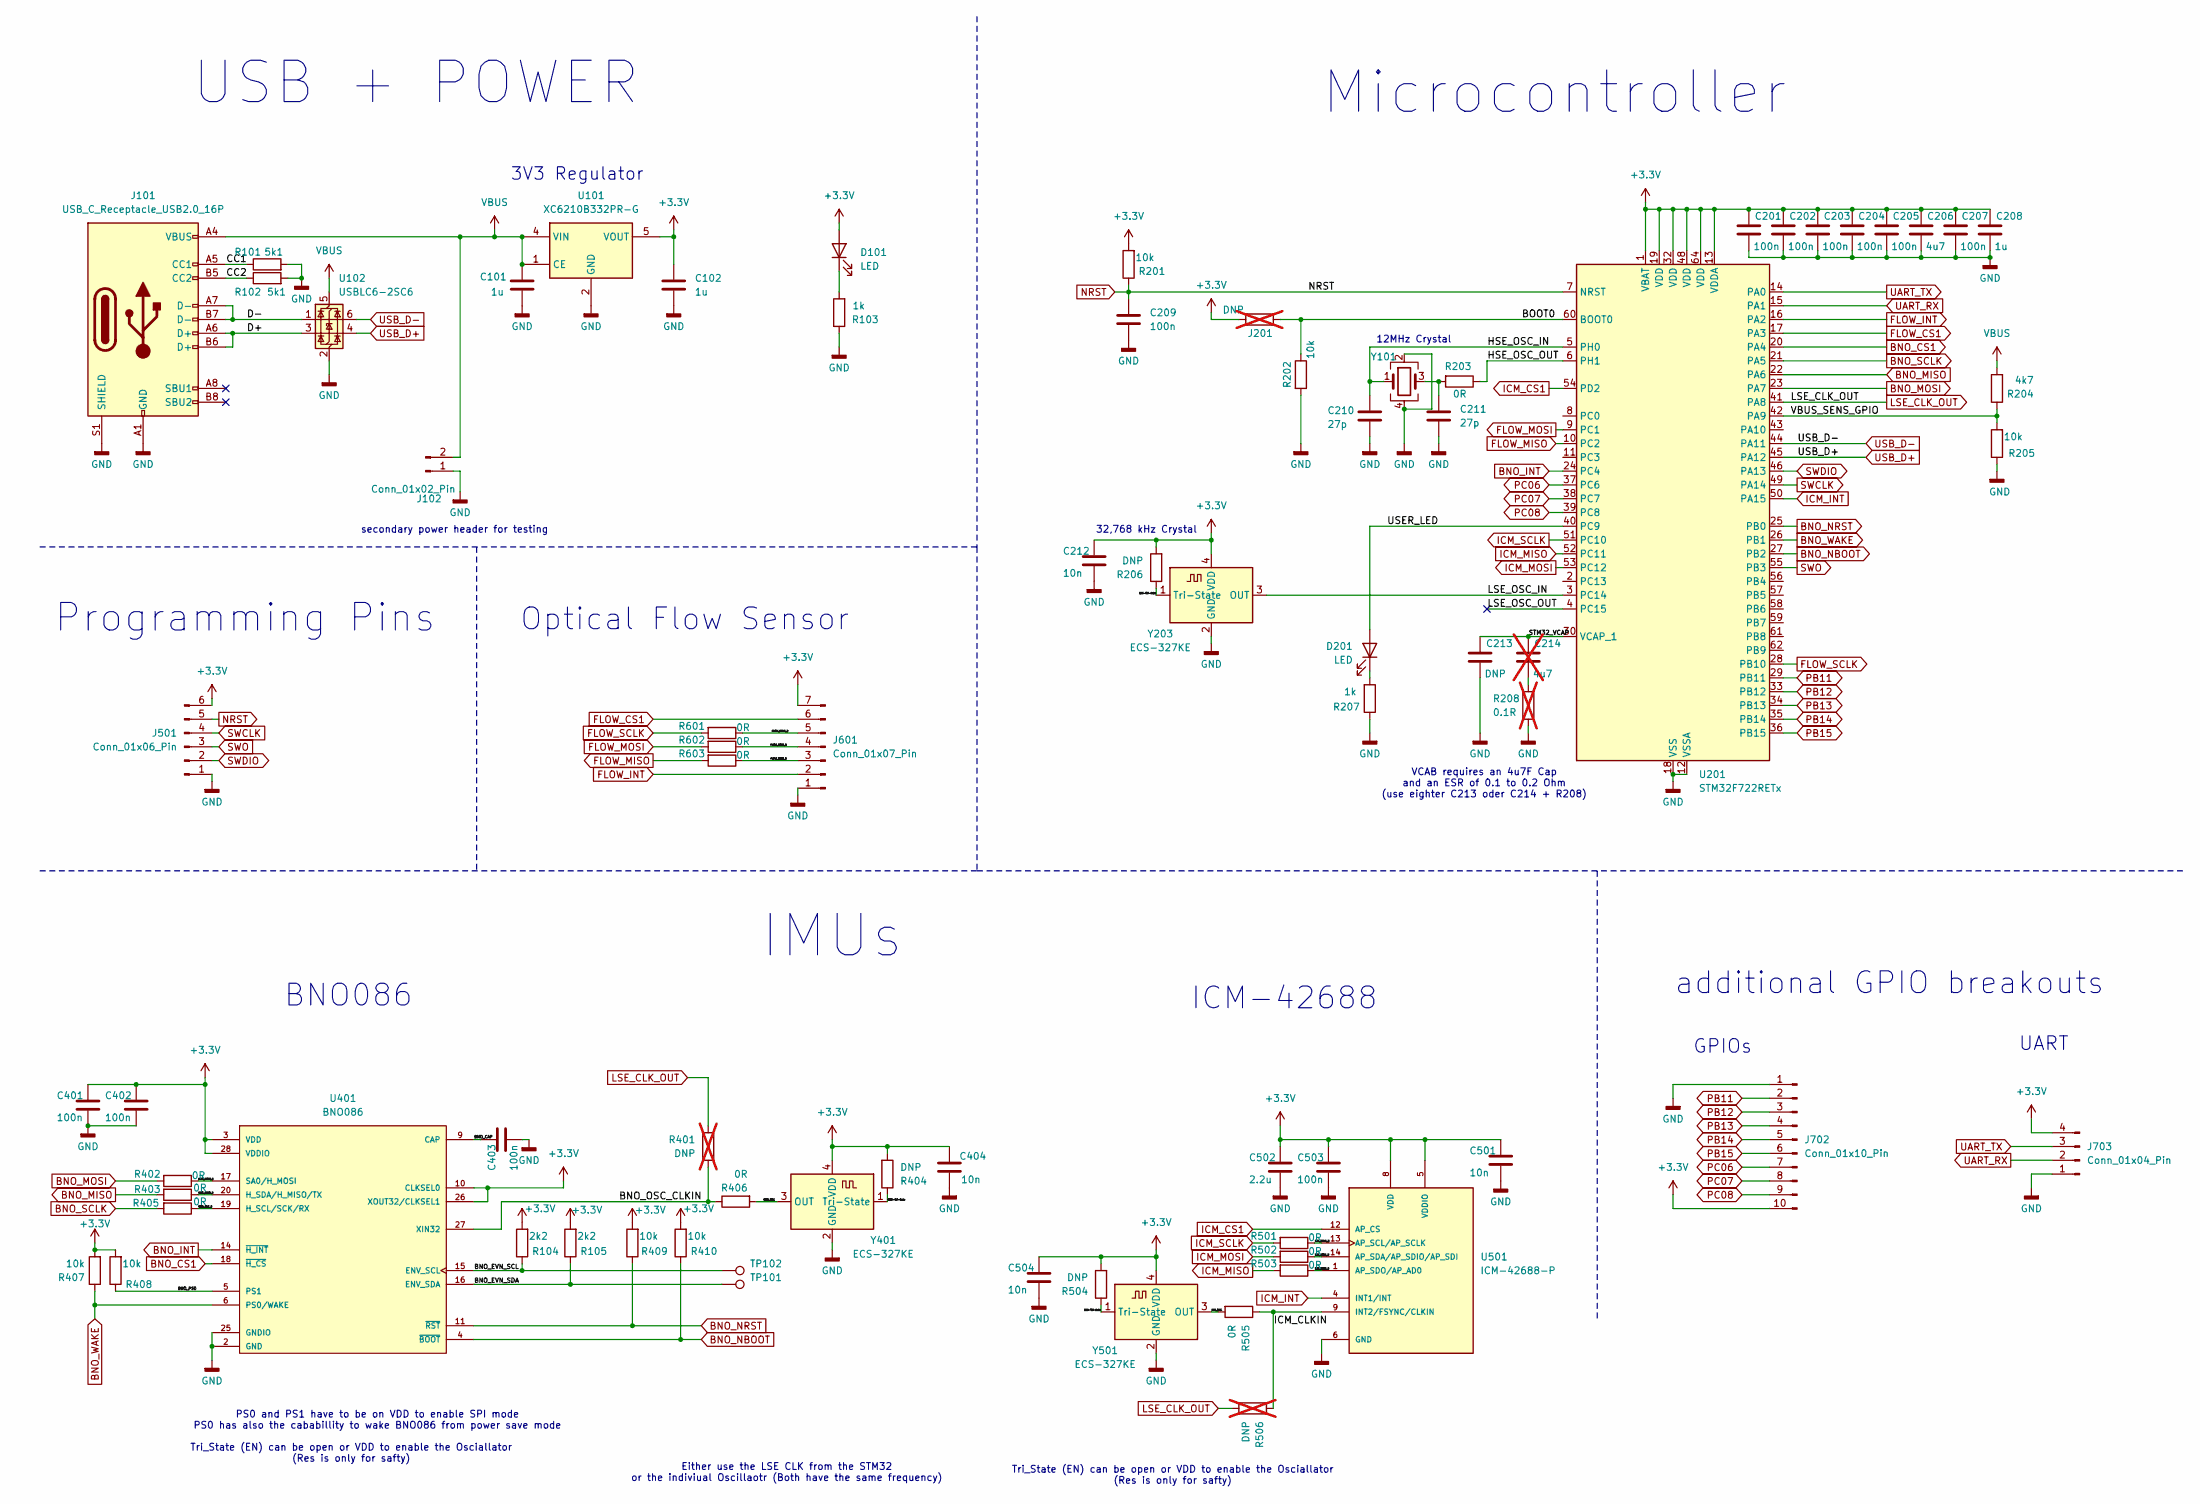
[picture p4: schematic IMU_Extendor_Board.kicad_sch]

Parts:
C101, C102: 1u; C_0805_2012Metric_Pad1.18x1.45mm_HandSolder
C201, C202, C203, C204, C205, C207, C209, C401, C402, C403, C503: 100n; 0402_1005Metric_Pad0.74x0.62mm_HandSolder
C206: 4u7; C_0603_1608Metric_Pad1.08x0.95mm_HandSolder
C208: 1u; C_0603_1608Metric_Pad1.08x0.95mm_HandSolder
C210, C211: 27p; 0402_1005Metric_Pad0.74x0.62mm_HandSolder
C212, C404, C501, C504: 10n; 0402_1005Metric_Pad0.74x0.62mm_HandSolder
C213: DNP; C_0603_1608Metric_Pad1.08x0.95mm_HandSolder
C214: 4u7; C_0603_1608Metric_Pad1.08x0.95mm_HandSolder; not fitted
C502: 2.2u; C_0603_1608Metric
D101, D201: LED; LED_0603_1608Metric
J101: USB_C_Receptacle_USB2.0_16P; USB_C_Receptacle_GCT_USB4105-xx-A_16P_TopMnt_Horizontal
J102: Conn_01x02_Pin; PinHeader_1x02_P2.54mm_Vertical
J201: DNP; R_0805_2012Metric_Pad1.20x1.40mm_HandSolder; not fitted
J501: Conn_01x06_Pin; PinHeader_1x06_P2.54mm_Vertical
J601: Conn_01x07_Pin; PinHeader_1x07_P2.54mm_Vertical
J702: Conn_01x10_Pin; PinHeader_1x10_P1.27mm_Vertical_SMD_Pin1Right
J703: Conn_01x04_Pin; PinHeader_1x04_P2.54mm_Vertical
R101, R102: 5k1; 0402_1005Metric_Pad0.74x0.62mm_HandSolder
R103, R207: 1k; 0402_1005Metric_Pad0.74x0.62mm_HandSolder
R104, R105: 2k2; 0402_1005Metric_Pad0.74x0.62mm_HandSolder
R201, R202, R205, R407, R408, R409, R410: 10k; 0402_1005Metric_Pad0.74x0.62mm_HandSolder
R203, R402, R403, R405, R406, R501, R502, R503, R505, R601, R602, R603: 0R; 0402_1005Metric_Pad0.74x0.62mm_HandSolder
R204: 4k7; 0402_1005Metric_Pad0.74x0.62mm_HandSolder
R206, R404, R504: DNP; 0402_1005Metric_Pad0.74x0.62mm_HandSolder
R208: 0.1R; 0402_1005Metric_Pad0.74x0.62mm_HandSolder; not fitted
R401, R506: DNP; 0402_1005Metric_Pad0.74x0.62mm_HandSolder; not fitted
TP101, TP102: TestPoint; TestPoint_Pad_1.0x1.0mm
U101: XC6210B332PR-G; SOT-89-5_Handsoldering
U102: USBLC6-2SC6; SOT-23-6
U201: STM32F722RETx; LQFP-64_10x10mm_P0.5mm
U401: BNO086
U501: ICM-42688-P; ICM-42688-p
Y101: Crystal_GND24; Crystal_SMD_Abracon_ABM8G-4Pin_3.2x2.5mm
Y203, Y401, Y501: ECS-327KE; Oscillator_SMD_ECS_2520MV-xxx-xx-4Pin_2.5x2.0mm

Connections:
+3.3V: C102.1, C201.1, C202.1, C203.1, C204.1, C205.1, C206.1, C207.1, C208.1, C212.1, C401.1, C402.1, C404.1, C501.1, C502.1, C503.1, C504.1, D101.2 (A), J201.1, J501.6, J601.7, J702.10, J703.4, R104.2, R105.2, R201.2, R206.2, R404.2, R407.2, R408.2, R409.2, R410.2, R504.2, U101.5 (VOUT), U201.1 (VBAT), U201.13 (VDDA), U201.19 (VDD), U201.32 (VDD), U201.48 (VDD), U201.64 (VDD), U401.3 (VDD), U401.10 (CLKSEL0), U401.26 (XOUT32/CLKSEL1), U401.28 (VDDIO), U501.5 (VDDIO), U501.8 (VDD), Y203.4 (VDD), Y401.4 (VDD), Y501.4 (VDD)
/BNO-Tri-Sate: R404.1, Y401.1 (Tri-State)
/BNO_CAP: C403.1, U401.9 (CAP)
/BNO_CLK_D: R405.1, U401.19 (H_SCL/SCK/RX)
/BNO_EVN_SCL: R104.1, TP102.1, U401.15 (ENV_SCL)
/BNO_EVN_SDA: R105.1, TP101.1, U401.16 (ENV_SDA)
/BNO_MISO_D: R403.1, U401.20 (H_SDA/H_MISO/TX)
/BNO_MOSI_D: R402.1, U401.17 (SA0/H_MOSI)
/BNO_OSC: R406.2, Y401.3 (OUT)
/BNO_OSC_CLKIN: R401.2, R406.1, U401.27 (XIN32)
/BNO_PS0: R408.1, U401.5 (PS1)
/BOOT0: J201.2, R202.1, U201.60 (BOOT0)
/CC1: J101.A5 (CC1), R101.1
/CC2: J101.B5 (CC2), R102.1
/D+: J101.A6 (D+), J101.B6 (D+), U102.3 (I/O2)
/D-: J101.A7 (D-), J101.B7 (D-), U102.1 (I/O1)
/FLOW_MISO_D: J601.3, R603.1
/FLOW_MOSI_D: J601.4, R602.1
/FLOW_SCLK_D: J601.5, R601.1
/HSE_OSC_IN: C210.1, U201.5 (PH0), Y101.1
/HSE_OSC_OUT: R203.1, U201.6 (PH1)
/ICM-Tri-Sate: R504.1, Y501.1 (Tri-State)
/ICM_CLKIN: R505.1, R506.1, U501.9 (INT2/FSYNC/CLKIN)
/ICM_MISO_D: R503.1, U501.1 (AP_SDO/AP_AD0)
/ICM_MOSI_D: R502.1, U501.14 (AP_SDA/AP_SDIO/AP_SDI)
/ICM_OSC: R505.2, Y501.3 (OUT)
/ICM_SCLK_D: R501.1, U501.13 (AP_SCL/AP_SCLK)
/LSE-Tri-Sate: R206.1, Y203.1 (Tri-State)
/LSE_OSC_IN: U201.3 (PC14), Y203.3 (OUT)
/LSE_OSC_OUT: U201.4 (PC15)
/STM32_VCAP: C213.1, C214.1, U201.30 (VCAP_1)
/USER_LED: D201.2 (A), U201.40 (PC9)
/VBUS_SENS_GPIO: R204.1, R205.2, U201.42 (PA9)
BNO_CS1: U201.20 (PA4), U401.18 (~H_CS)
BNO_INT: U201.24 (PC4), U401.14 (~H_INT)
BNO_MISO: R403.2, U201.22 (PA6)
BNO_MOSI: R402.2, U201.23 (PA7)
BNO_NBOOT: R410.1, U201.27 (PB2), U401.4 (~BOOT)
BNO_NRST: R409.1, U201.25 (PB0), U401.11 (~RST)
BNO_SCLK: R405.2, U201.21 (PA5)
BNO_WAKE: R407.1, U201.26 (PB1), U401.6 (PS0/WAKE)
FLOW_CS1: J601.6, U201.17 (PA3)
FLOW_INT: J601.2, U201.16 (PA2)
FLOW_MISO: R603.2, U201.10 (PC2)
FLOW_MOSI: R602.2, U201.9 (PC1)
FLOW_SCLK: R601.2, U201.28 (PB10)
GND: C101.2, C102.2, C201.2, C202.2, C203.2, C204.2, C205.2, C206.2, C207.2, C208.2, C209.2, C210.2, C211.2, C212.2, C213.2, C401.2, C402.2, C403.2, C404.2, C501.2, C502.2, C503.2, C504.2, J101.A1 (GND), J101.A12 (GND), J101.B1 (GND), J101.B12 (GND), J101.S1 (SHIELD), J102.1, J501.1, J601.1, J702.1, J703.1, R101.2, R102.2, R103.1, R202.2, R205.1, R207.1, R208.2, U101.2 (GND), U102.2 (GND), U201.12 (VSSA), U201.18 (VSS), U201.31 (VSS), U201.47 (VSS), U201.63 (VSS), U401.2 (GND), U401.25 (GNDIO), U501.6 (GND), Y101.2, Y101.4, Y203.2 (GND), Y401.2 (GND), Y501.2 (GND)
ICM_CS1: U201.54 (PD2), U501.12 (AP_CS)
ICM_INT: U201.50 (PA15), U501.4 (INT1/INT)
ICM_MISO: R503.2, U201.52 (PC11)
ICM_MOSI: R502.2, U201.53 (PC12)
ICM_SCLK: R501.2, U201.51 (PC10)
LSE_CLK_OUT: R401.1, R506.2, U201.41 (PA8)
NRST: C209.1, J501.5, R201.1, U201.7 (NRST)
unnamed: C211.1, R203.2, Y101.3
unnamed: C214.2, R208.1
unnamed: D101.1 (K), R103.2
unnamed: D201.1 (K), R207.2
PB11: J702.2, U201.29 (PB11)
PB12: J702.3, U201.33 (PB12)
PB13: J702.4, U201.34 (PB13)
PB14: J702.5, U201.35 (PB14)
PB15: J702.6, U201.36 (PB15)
PC06: J702.7, U201.37 (PC6)
PC07: J702.8, U201.38 (PC7)
PC08: J702.9, U201.39 (PC8)
SWCLK: J501.4, U201.49 (PA14)
SWDIO: J501.2, U201.46 (PA13)
SWO: J501.3, U201.55 (PB3)
UART_RX: J703.2, U201.15 (PA1)
UART_TX: J703.3, U201.14 (PA0)
USB_D+: U102.4 (I/O2), U201.45 (PA12)
USB_D-: U102.6 (I/O1), U201.44 (PA11)
VBUS: C101.1, J101.A4 (VBUS), J101.A9 (VBUS), J101.B4 (VBUS), J101.B9 (VBUS), J102.2, R204.2, U101.1 (CE), U101.4 (VIN), U102.5 (VBUS)

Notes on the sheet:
ICM-42688
additional GPIO breakouts
PS0 and PS1 have to be on VDD to enable SPI mode PS0 has also the cababillity to wake BNO086 from power save mode
Either use the LSE CLK from the STM32 or the indiviual Oscillaotr (Both have the same frequency)
secondary power header for testing
Optical Flow Sensor
12MHz Crystal
BNO086
VCAB requires an 4u7F Cap and an ESR of 0.1 to 0.2 Ohm (use eighter C213 oder C214 + R208)
Tri_State (EN) can be open or VDD to enable the Osciallator (Res is only for safty)
Microcontroller
Programming Pins
3V3 Regulator
GPIOs
IMUs
UART
USB + POWER
32,768 kHz Crystal

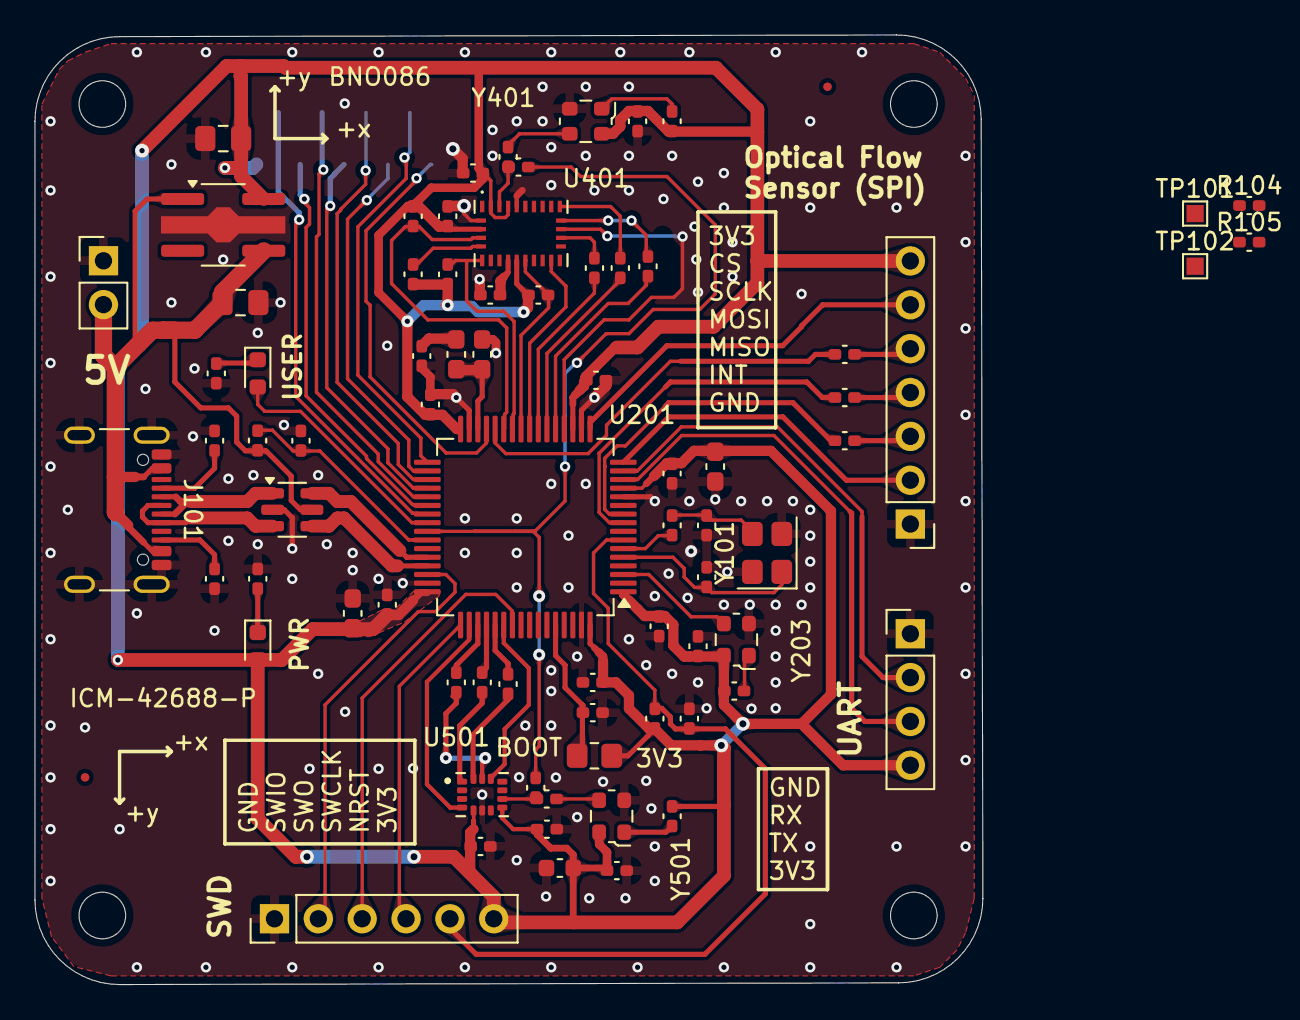
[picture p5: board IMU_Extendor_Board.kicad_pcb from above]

Board: 2 copper layers, 54.9 x 55.0 mm, 76 parts (1 on the bottom side), 73 nets.

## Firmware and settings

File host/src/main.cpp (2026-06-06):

#include "calib_bridge/Application.h"
#include "calib_bridge/Config.h"

#include <spdlog/spdlog.h>

#include <csignal>
#include <cstdlib>
#include <iostream>
#include <string>

namespace
{
    calib_bridge::Application* g_app = nullptr;

    void on_signal(int)
    {
        if (g_app) g_app->request_stop();
    }

    void set_log_level(const std::string& level)
    {
        if      (level == "trace") spdlog::set_level(spdlog::level::trace);
        else if (level == "debug") spdlog::set_level(spdlog::level::debug);
        else if (level == "info")  spdlog::set_level(spdlog::level::info);
        else if (level == "warn" ||
                 level == "warning") spdlog::set_level(spdlog::level::warn);
        else if (level == "error" ||
                 level == "err")   spdlog::set_level(spdlog::level::err);
    }

    void print_usage()
    {
        std::cout
            << "raccoon-calib-bridge — USB-CDC → raccoon-transport publisher\n"
               "\n"
               "Usage: raccoon-calib-bridge [--port PATH] [--log LEVEL]\n"
               "                            [--provider URL] [--version]\n"
               "\n"
               "ENV überschreibt CLI:\n"
               "  CALIB_BRIDGE_PORT          /dev/ttyACM0 (default: auto-detect via VID:PID)\n"
               "  CALIB_BRIDGE_LOG           trace|debug|info|warn|error\n"
               "  CALIB_BRIDGE_RECONNECT_MS  ms between port-open retries\n"
               "  CALIB_BRIDGE_STATUS_MS     ms between status publishes\n"
               "  CALIB_BRIDGE_SILENCE_MS    silence → force reopen\n"
               "  CALIB_BRIDGE_TRANSPORT     raccoon transport provider URL\n";
    }
}

int main(int argc, char** argv)
{
    calib_bridge::Config cfg = calib_bridge::Config::from_env();

    for (int i = 1; i < argc; ++i)
    {
        const std::string a = argv[i];
        const auto next = [&](const char* what) -> std::string {
            if (i + 1 >= argc)
            {
                std::cerr << "missing value for " << what << "\n";
                std::exit(EXIT_FAILURE);
            }
            return argv[++i];
        };

        if      (a == "--port"     || a == "-p") cfg.serial_port = next("--port");
        else if (a == "--log"      || a == "-l") cfg.log_level = next("--log");
        else if (a == "--provider")              cfg.transport_provider = next("--provider");
        else if (a == "--version")               { std::cout << "raccoon-calib-bridge 0.1.0\n"; return 0; }
        else if (a == "--help"     || a == "-h") { print_usage(); return 0; }
        else
        {
            std::cerr << "unknown argument: " << a << "\n";
            print_usage();
            return EXIT_FAILURE;
        }
    }

    spdlog::set_pattern("[%Y-%m-%d %H:%M:%S.%e] [%^%l%$] %v");
    set_log_level(cfg.log_level);

    std::signal(SIGINT,  on_signal);
    std::signal(SIGTERM, on_signal);

    try
    {
        calib_bridge::Application app{std::move(cfg)};
        g_app = &app;
        const int rc = app.run();
        g_app = nullptr;
        return rc;
    }
    catch (const std::exception& e)
    {
        spdlog::error("fatal: {}", e.what());
        return EXIT_FAILURE;
    }
}

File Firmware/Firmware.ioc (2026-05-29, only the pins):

Mcu.UserName=STM32F722RETx
PA0-WKUP.Signal=UART4_TX
PA1.Signal=UART4_RX
PA11.Signal=USB_OTG_FS_DM
PA12.Signal=USB_OTG_FS_DP
PA13.Signal=SYS_JTMS-SWDIO
PA14.Signal=SYS_JTCK-SWCLK
PA15.GPIO_Label=ICM_INT
PA15.Signal=GPXTI15
PA2.GPIO_Label=FLOW_SENS_INT
PA2.Signal=GPIO_Input
PA3.GPIO_Label=FLOW_SENS_CS
PA3.Signal=GPIO_Output
PA4.GPIO_Label=BNO_CS1
PA4.Signal=GPIO_Output
PA5.GPIO_Label=BNO_SCLK
PA5.Signal=SPI1_SCK
PA6.GPIO_Label=BNO_MISO
PA6.Signal=SPI1_MISO
PA7.GPIO_Label=BNO_MOSI
PA7.Signal=SPI1_MOSI
PA9.Signal=USB_OTG_FS_VBUS
PB0.GPIO_Label=BNO_NRST
PB0.Signal=GPIO_Output
PB1.GPIO_Label=BNO_WAKE
PB1.Signal=GPIO_Output
PB10.Signal=SPI2_SCK
PB11.GPIO_Label=add_PB11
PB11.Signal=GPIO_Output
PB12.GPIO_Label=add_PB12
PB12.Signal=GPIO_Output
PB13.GPIO_Label=add_PB13
PB13.Signal=GPIO_Output
PB14.GPIO_Label=add_PB14
PB14.Signal=GPIO_Output
PB15.GPIO_Label=add_PB15
PB15.Signal=GPIO_Output
PB2.GPIO_Label=BNO_NBOOT
PB2.Signal=GPIO_Output
PB3.Signal=SYS_JTDO-SWO
PC1.GPIO_Label=FLOW_MOSI
PC1.Signal=SPI2_MOSI
PC10.Signal=SPI3_SCK
PC11.Signal=SPI3_MISO
PC12.Signal=SPI3_MOSI
PC14-OSC32_IN.Signal=RCC_OSC32_IN
PC15-OSC32_OUT.Signal=RCC_OSC32_OUT
PC2.Signal=SPI2_MISO
PC4.GPIO_Label=BNO_INT
PC4.Signal=GPXTI4
PC6.GPIO_Label=add_PC6
PC6.Signal=GPIO_Output
PC7.GPIO_Label=add_PC7
PC7.Signal=GPIO_Output
PC8.GPIO_Label=add_PC8
PC8.Signal=GPIO_Output
PC9.GPIO_Label=USER_LED
PC9.Signal=GPIO_Output
PD2.GPIO_Label=SPI3_CS1
PD2.Signal=GPIO_Output
PH0-OSC_IN.Signal=RCC_OSC_IN
PH1-OSC_OUT.Signal=RCC_OSC_OUT

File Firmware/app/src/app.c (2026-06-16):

#include "app.h"

#include <stdio.h>
#include <stddef.h>

#include "main.h"
#include "stm32f7xx_hal.h"

#include "module.h"
#include "swo.h"

/* Modul-Registry — neue Sensoren / Funktionen hier registrieren.  Jedes
 * Modul liefert ein eigenes `setup()` (einmalig beim Boot) und `loop()`
 * (pro Iteration). `enabled` schaltet ein Modul übergangsweise weg, ohne
 * den Eintrag zu löschen. */
extern const module_t bno_module;
extern const module_t paa_module;
extern const module_t paa_cal_module;
extern const module_t icm_module;
extern const module_t status_module;
extern const module_t usb_module;

/* usb_module FIRST: setup() starts the CDC stack, so it's available when
 * the sensor modules later try to push samples. */
static const module_t *const MODULES[] = {
    &usb_module,
    &bno_module,
    &paa_module,
    &paa_cal_module,
    &icm_module,
    &status_module,
};
#define NUM_MODULES (sizeof(MODULES) / sizeof(MODULES[0]))

/* Soft-Start: Module gestaffelt hochfahren statt alle gleichzeitig.  Jeder
 * Sensor/Peripherie-Block zieht beim Bring-up Strom; gleichzeitig = ein
 * Step, der eine grenzwertige Versorgung in den Brownout zieht.  Die kurze
 * Pause lässt den Strom jedes Blocks setteln, bevor der nächste dazukommt
 * → flacherer Anstieg.  (Der Kondensator-Inrush beim Einstecken liegt VOR
 * dieser Phase und ist reine Hardware — das glättet sie NICHT.) */
#define SETUP_STAGGER_MS  25u

static void run_setup(void)
{
    for (size_t i = 0; i < NUM_MODULES; i++) {
        const module_t *m = MODULES[i];
        if (!m->enabled) {
            printf("[setup] %s SKIPPED (disabled)\r\n", m->name);
            continue;
        }
        if (m->setup) m->setup();
        HAL_Delay(SETUP_STAGGER_MS);
    }
}

static void run_loop_iteration(void)
{
    for (size_t i = 0; i < NUM_MODULES; i++) {
        const module_t *m = MODULES[i];
        if (!m->enabled || !m->loop) continue;
        m->loop();
    }
}

void app_main(void)
{
    /* SWO/ITM printf on PB3.  ST-LINK V2 (Clone) routet das in der Praxis
     * nicht durch; ST-LINK V3 schon.  UART4 ist die zuverlässige Quelle. */
    swo_init(HAL_RCC_GetHCLKFreq(), 1000000U);
    setvbuf(stdout, NULL, _IONBF, 0);
    printf("[boot] calibration-board up, HCLK=%lu Hz\r\n",
           (unsigned long)HAL_RCC_GetHCLKFreq());

    run_setup();

    while (1) {
        run_loop_iteration();
        /* Kein __WFI: PAA wird jede Iteration gelesen (~1 kHz, Wunsch:
         * maximale Rate) → der Loop hat ohnehin kaum Leerlauf, WFI würde
         * also kaum Strom sparen, machte aber SWD-HOTPLUG-Debugging
         * unzuverlässig (schlafender Core).  Power-Saving kam über den
         * 192->96-MHz-Takt — der scheiterte aber an der PAA-SPI; daher
         * vorerst bei 192 MHz. */
    }
}

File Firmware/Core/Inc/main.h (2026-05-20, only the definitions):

#define FLOW_MOSI_Pin GPIO_PIN_1
#define FLOW_MOSI_GPIO_Port GPIOC
#define FLOW_SENS_INT_Pin GPIO_PIN_2
#define FLOW_SENS_INT_GPIO_Port GPIOA
#define FLOW_SENS_CS_Pin GPIO_PIN_3
#define FLOW_SENS_CS_GPIO_Port GPIOA
#define BNO_CS1_Pin GPIO_PIN_4
#define BNO_CS1_GPIO_Port GPIOA
#define BNO_SCLK_Pin GPIO_PIN_5
#define BNO_SCLK_GPIO_Port GPIOA
#define BNO_MISO_Pin GPIO_PIN_6
#define BNO_MISO_GPIO_Port GPIOA
#define BNO_MOSI_Pin GPIO_PIN_7
#define BNO_MOSI_GPIO_Port GPIOA
#define BNO_INT_Pin GPIO_PIN_4
#define BNO_INT_GPIO_Port GPIOC
#define BNO_INT_EXTI_IRQn EXTI4_IRQn
#define BNO_NRST_Pin GPIO_PIN_0
#define BNO_NRST_GPIO_Port GPIOB
#define BNO_WAKE_Pin GPIO_PIN_1
#define BNO_WAKE_GPIO_Port GPIOB
#define BNO_NBOOT_Pin GPIO_PIN_2
#define BNO_NBOOT_GPIO_Port GPIOB
#define add_PB11_Pin GPIO_PIN_11
#define add_PB11_GPIO_Port GPIOB
#define add_PB12_Pin GPIO_PIN_12
#define add_PB12_GPIO_Port GPIOB
#define add_PB13_Pin GPIO_PIN_13
#define add_PB13_GPIO_Port GPIOB
#define add_PB14_Pin GPIO_PIN_14
#define add_PB14_GPIO_Port GPIOB
#define add_PB15_Pin GPIO_PIN_15
#define add_PB15_GPIO_Port GPIOB
#define add_PC6_Pin GPIO_PIN_6
#define add_PC6_GPIO_Port GPIOC
#define add_PC7_Pin GPIO_PIN_7
#define add_PC7_GPIO_Port GPIOC
#define add_PC8_Pin GPIO_PIN_8
#define add_PC8_GPIO_Port GPIOC
#define USER_LED_Pin GPIO_PIN_9
#define USER_LED_GPIO_Port GPIOC
#define ICM_INT_Pin GPIO_PIN_15
#define ICM_INT_GPIO_Port GPIOA
#define SPI3_CS1_Pin GPIO_PIN_2
#define SPI3_CS1_GPIO_Port GPIOD

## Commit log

2026-05-20 add initial project files and setup scripts for STM32 calibration board firmware
2026-05-20 add application logic and hardware driver integration for BNO08x and PAA5100
    [enclosure.scad, enclosure_bottom.stl, enclosure_lid.stl]
2026-05-20 update GPIO configurations and SPI settings for improved functionality
2026-05-21 bno08x bringup: NRST/BOOTN PinState fix + diagnostic counters
    - .ioc: PB0 (BNO_NRST) PinState=SET — without this, MX_GPIO_Init holds
    the BNO in reset until bno08x_init runs, leaving the chip in an
    inconsistent power-on state. Sibling fix to the existing BOOTN/PB2
    default-HIGH config.
    - main.c: HSI workaround for SystemClock_Config restored (HSE crystal
    Y202 still not soldered cleanly — Issue 1). Reverted on every CubeMX
    regen until .ioc is switched to HSI.
    - bno08x.c: granular diagnostic counters for hal_read/hal_write exit
    paths (g_read_hdr_zero, g_write_int_gated, g_writes_ack_int, etc.)
    plus a capture buffer for actual packet headers + payload.
    - bno08x.c: EXTI4_IRQHandl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
    [Firmware.ioc, bno08x.c]
2026-05-21 optical flow + hse working
    [enclosure.scad, enclosure_bottom.stl, enclosure_lid.step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]
2026-05-21 app: Arduino-style module architecture
    Verschiebt die Sensor-Init-Logik aus app.c in pro-Modul .c-Files mit
    einem leichtgewichtigen `module_t` Interface (setup/loop/enabled).
    `app.c` führt nur noch die Registry-Iteration durch.
    - `app/inc/module.h`: module_t struct
    - `app/src/bno_module.c`: BNO086-Wrapper, enabled=false bis HW-Issue 2
    (CS-Pfad) gelöst ist
    - `app/src/paa_module.c`: PAA5100-Wrapper, 10 Hz Motion-Print
    - `app/src/app.c`: generischer setup-then-loop Runner
    Neue Sensoren: einfach `xyz_module.c` mit `setup()`, `loop()`,
    `module_t xyz_module = {…}` anlegen + im MODULES[]-Array in app.c
    registrieren. CMake-Glob in `app/src/*.c` zieht die Datei automatisch.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
    [app.c, bno_module.c, paa_module.c]
2026-05-21 modifide the schematic to fix oscillator GND and in pcb; added ENV I2C pullpus in shematic
    [IMU_Extendor_Board.kicad_pcb, IMU_Extendor_Board.kicad_sch]
2026-05-21 cs line works but MISO doesn't send any data; added pullups on int and miso lines because claude told me too
    [Firmware.ioc, app.c, bno08x.c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]
2026-05-29 add USB device support with CDC class integration and descriptors
2026-06-06 add ICM42688P sensor support and update USB module for binary frame streaming
2026-06-06 update IMU data handling to include bias_z and adjust payload sizes for orientation frame
2026-06-16 add PAA_ACC frame support and implement signed counts accumulator for motion tracking
2026-07-16 docs: reframe README around the board's actual purpose
    It's a Wombat companion board — PAA-based absolute position and a
    reference IMU for calibrating the onboard one, enabling motion
    teach-in and automated setup routines. Not a bench eval board.

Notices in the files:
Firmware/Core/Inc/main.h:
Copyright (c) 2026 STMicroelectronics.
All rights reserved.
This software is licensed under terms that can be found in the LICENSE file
